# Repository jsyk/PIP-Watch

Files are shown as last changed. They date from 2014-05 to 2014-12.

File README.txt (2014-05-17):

----------------------------------------
Personal Information Panel - PIP Watch
----------------------------------------

Personal Information Panel – PIP Watch – is an open-source smart watch with an ePaper (EPD) display, a Bluetooth connection, and a Li-Ion accumulator.

This is a work in progress... For more information please visit:
http://www.jsykora.info/?page_id=328

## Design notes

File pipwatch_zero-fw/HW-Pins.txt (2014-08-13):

PA0     In      USART2_CTS
PA1     Out     USART2_RTS
PA2     Out     USART2_TX
PA3     In      USART2_RX

PA4     Out     GPIO EPD_nCS
PA5     Out     SPI1_SCK
PA6     In      GPIO Busy
PA7     Out     SPI1_MOSI

PB0     Ana     ADC_IN8 - Battery/5

PB2     Out     GPIO nRES
PB10    Out     GPIO EPD_DC

PB11    In      GPIO Btn0

PB13    Out     GPIO/TIM1_CH1N Motor_1

------
PC13    Out     Tamper-RTC

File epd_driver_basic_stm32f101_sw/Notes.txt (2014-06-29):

st-flash write stm32test_flash.bin 0x08000000

openocd -f interface/stlink-v2.cfg -f target/stm32f1x_stlink.cfg

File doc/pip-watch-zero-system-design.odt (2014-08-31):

Pip-Watch Zero: System Design

Pip-Watch Zero (Personal Information Panel) is an open-source smart watch with an ePaper (EPD) display, a bluetooth modem for connecting with smartphones, all powered by a Li-Ion accumulator.

...Show

Pip-Watch uses a small ePaper/eInk electrophoretic display (EPD). Electrophoretic displays have high contrast even in sun light, and very low power consumption, making them suitable for always-on battery-powered embedded devices. Low power consumption comes from the fact that the EPD draws no power when just displaying still image; it needs energy only when redrawing the screen.

...Talk

Communication with a mobile phone (or any internet-connected device) is via a Bluetooth modem module. As the modem implements the standard Bluetooth Serial Port Profile (SPP), Pip-Watch can be controlled over any terminal application even by hand. A smartphone app will transmit notifications to Pip-watch when an SMS arrives, a calendar event pops out, or an incoming call is being received.

...Eat
Pip-Watch is powered by a small Li-Ion accumulator that is recharged via a standard Micro USB connector. When connected, the USB can be also used to communicate with the device.

Hardware Block Schema

Hardware is built around the STM32F103 microcontroller. CPU timing is derived from an 8MHz crystal; it provides a clock stable enough for an on-chip USB interface to function correctly. An auxiliary low-speed precision 32.768kHz crystal is used for real-time clock (RTC), which is also included in the microcontroller.

Bluetooth modem is implemented by a pre-built commercial module. The first prototype uses OEMSPA310 from connectBlue, later the BTM431 from Laird will be used. The BTM431 has the advantage of lower power consumption and smaller size. These modules implement complete Bluetooth stack beginning with built-in ceramic antenna, and ending with a UART interface. Both modules are controlled via AT-style modem commands (albeit different between the types).

All power is normally delivered from Li-On battery, type Nokia BL-4C. The battery is charged form a Micro-USB connector via a charging controller MCP73831. The whole device runs at 3.3V, which is generated by a low-drop regulator LD59015C33R from a battery voltage. Current battery voltage is monitored by an A/D converter in the microcontroller, so the remaining battery charge can be computed and displayed on screen.

The display is implemented by GDE021A1, a small 3” electrophoretic display with the resolution 172x72 pixels. Communication with the display is via simple SPI-like interface. The display requires a charge pump with a coil and MOSFET.

Besides the display, the rest of human interface comprises of at least three buttons, three LEDs, and a vibrating motor(s) to give tactile notifications.

Software Block Schema

Software is organized in three layers. At the bottom there is a hardware access library from STM. The middle layer is composed mainly of the FreeRTOS operating system and a graphics drawing library u8g, both open-source. FreeRTOS is a simple multi-tasking operating system with pre-emptive scheduling, and with support for simple inter-task communication primitives such as queues and semaphores. The u8g is a drawing library: it is used to draw text and graphics such as lines and circles into a frame-buffer. The frame-buffer is then transmitted to the display.

The top software layer are tasks. The main tasks include a “Bluetooth Modem” task which communicates with a smartphone via Bluetooth, a “Battery” task that monitors battery charge using A/D converter, and a “Display Drawing” task that refreshes the display. Other tasks may be added as needed.

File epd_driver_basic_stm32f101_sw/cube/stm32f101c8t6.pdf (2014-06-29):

## stm32f101c8t6 Project

# 1. Description

## 1.1. Project

Project Name | stm32f101c8t6
Generated with: | STM32CubeMX 4.3.0
Date | 06/21/2014

## 1.2. MCU

MCU Serie | STM32F1
MCU Line | STM32F101
MCU name | STM32F101C8Tx
MCU Package | LQFP48
MCU Pin number | 48

# 2. Pinout Configuration

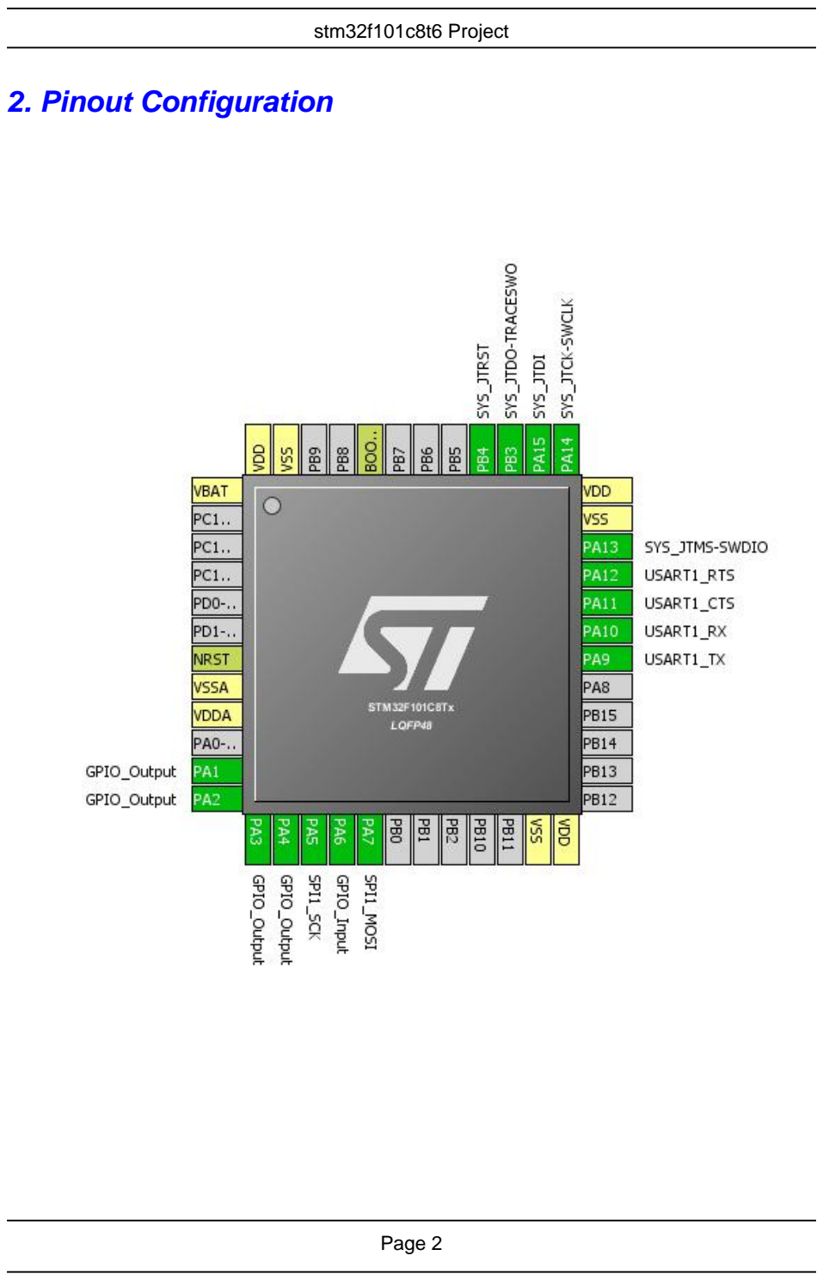
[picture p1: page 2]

# 3. IPs and Middlewares Configuration

IP | Mode | Fonction | Pin
SPI1 | Mode: TX-Only-Simplex-Unidirect-Master | SPI1_MOSI | PA7
| | SPI1_SCK | PA5
SYS | Debug: JTAG(5-pin) | SYS_JTCK-SWCLK | PA14
| | SYS_JTDI | PA15
| | SYS_JTDO-TRACESWO | PB3
| | SYS_JTMS-SWDIO | PA13
| | SYS_JTRST | PB4
USART1 | Mode: Hardware-flow-control | USART1_CTS | PA11
| | USART1_RTS | PA12
| | USART1_RX | PA10
| | USART1_TX | PA9

# 4. Pins Configuration

Pin | Pos Function(s) | | Label
PA1 * | 11 | GPIO_Output
PA2 * | 12 | GPIO_Output
PA3 * | 13 | GPIO_Output
PA4 * | 14 | GPIO_Output
PA5 | 15 | SPI1_SCK
PA6 * | 16 | GPIO_Input
PA7 | 17 | SPI1_MOSI
PA9 | 30 | USART1_TX
PA10 | 31 | USART1_RX
PA11 | 32 | USART1_CTS
PA12 | 33 | USART1_RTS
PA13 | 34 | SYS_JTMS-SWDIO
PA14 | 37 | SYS_JTCK-SWCLK
PA15 | 38 | SYS_JTDI
PB3 | 39 | SYS_JTDO-TRACESWO
PB4 | 40 | SYS_JTRST

## * The pin is affected with an I/O function

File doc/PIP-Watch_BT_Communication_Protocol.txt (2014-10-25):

PIP-Watch BT Communication Protocol
======================================

BTM430 Unsolicitated Messages
-------------------------------

The following messages may be sent by BTM430 at any time:

<cr,lf>AUDIO ON<cr,lf>
<cr,lf>AUDIO OFF<cr,lf>
<cr,lf>AUDIO FAIL<cr,lf>

<cr,lf>RING <btaddr><cr,lf>
<cr,lf>PIN? <btaddr><cr,lf>
<cr,lf>PAIR <n> <btaddr><cr,lf>
<cr,lf>PAIR 0 <btaddr> <MM><cr,lf>
<cr,lf>RX<string><cr,lf>
<cr,lf>CONNECT <btaddr><cr,lf>
<cr,lf>NO CARRIER<cr,lf>

Layers
-----------

Physical layer
    BTM431 BT modem

Link layer
    Transport of characters (bytes) via BT SPP link. - implemented in the modem.

Network layer
    Searching for nearby devices, enumeration, pairing, accepting connections.

Transport layer
    Transport of complete messages.

Session layer
    Synchronized exchange of messages between devices.
    Retransmission of lost messages.

Presentation layer

Application layer
    Transport of SMS etc.
    JSON

LINK STREAM LAYER
====================

<btm_rx_stream> :=
    { <btm_rx_msg> }*
    ON ERROR:
        a) eat till <lf>
        b) restart parser

<btm_rx_msg> :=
    . {<new_msg> | <msg_ack> | <msg_nack> | <btm_status>}

<new_msg> :=
    '*' <seqnum> <code_text> <lf>

<seqnum> :=
    <digit> <digit>

<msg_ack> :=
    '+' <seqnum> <lf>

<msg_nack> :=
    '-' <seqnum> <lf>

<btm_status> :=
    <cr><lf><status_text><cr><lf>

<code_text> := non-visible chars below space  must be code using escape secquence.
    Their presence here is either an error, or a token <cr>, <lf>.
    Escape sequences will be expanded in application (presentation) layer, not in the stream layer!

New Message:
-------------
*<seqnum><text...><lf>

<seqnum> = 00
    Two decimal numbers. Random number for the first message after connection,
    then incrementing, with a wrap.

<text>
    Max message length 2048 characters.
    Non-visible characters below space and the backslash are coded using \<2-hex-num>

Msg acknowledgement
-----------------------
+<seqnum><lf>

Msg nack
-----------
-<seqnum><lf>

APPLICATION LAYER
===================

Examples
===============

*01Ahoj<lf>

*01{"time":"2204"}<lf>

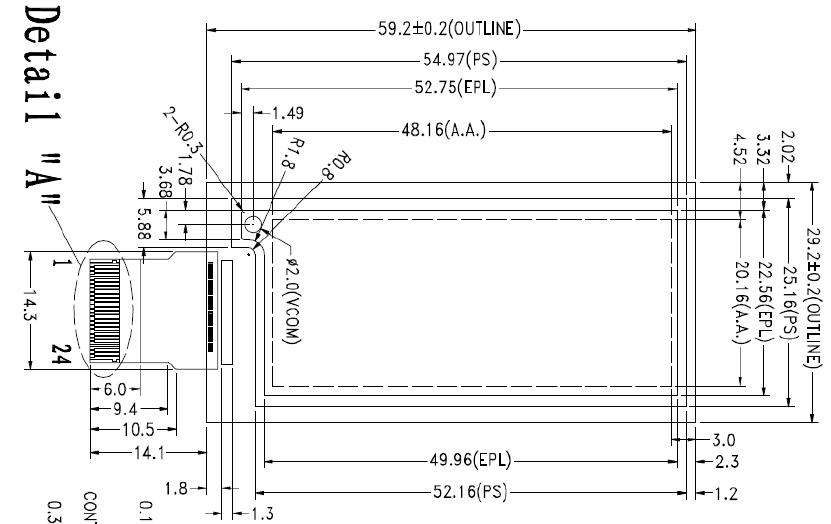
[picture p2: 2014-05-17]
doc/GDE021A1_mechanical.png

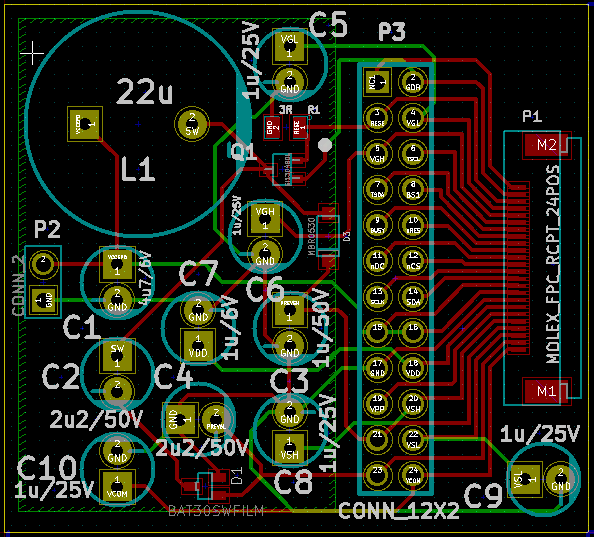
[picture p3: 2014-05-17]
doc/epd_driver_prototype_pcb.png

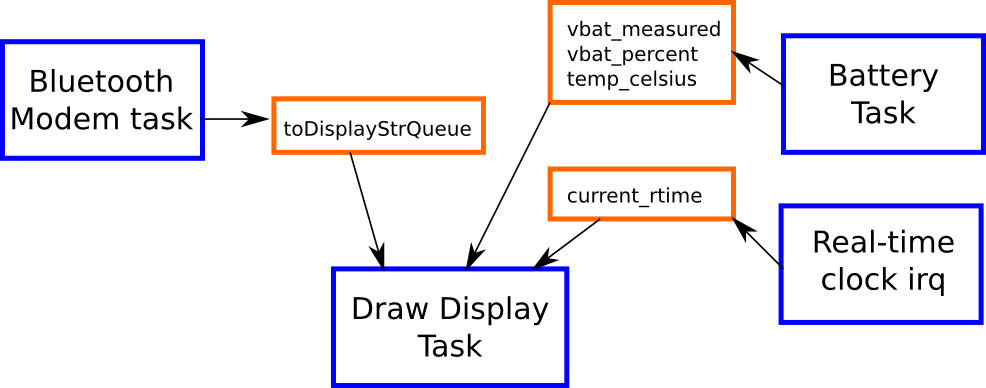
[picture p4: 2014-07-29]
doc/swtasks.png

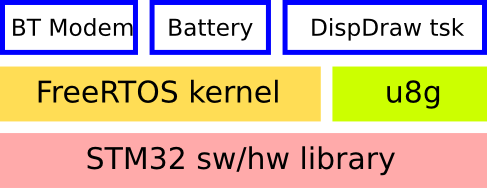
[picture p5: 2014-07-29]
doc/swarch.png

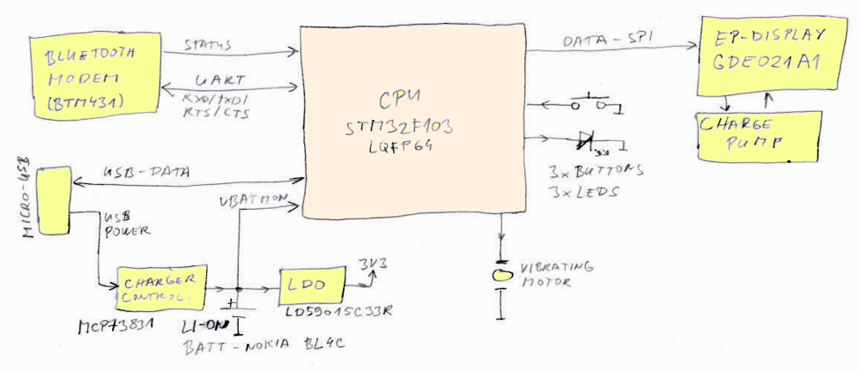
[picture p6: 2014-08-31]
doc/hw-block-schema.png

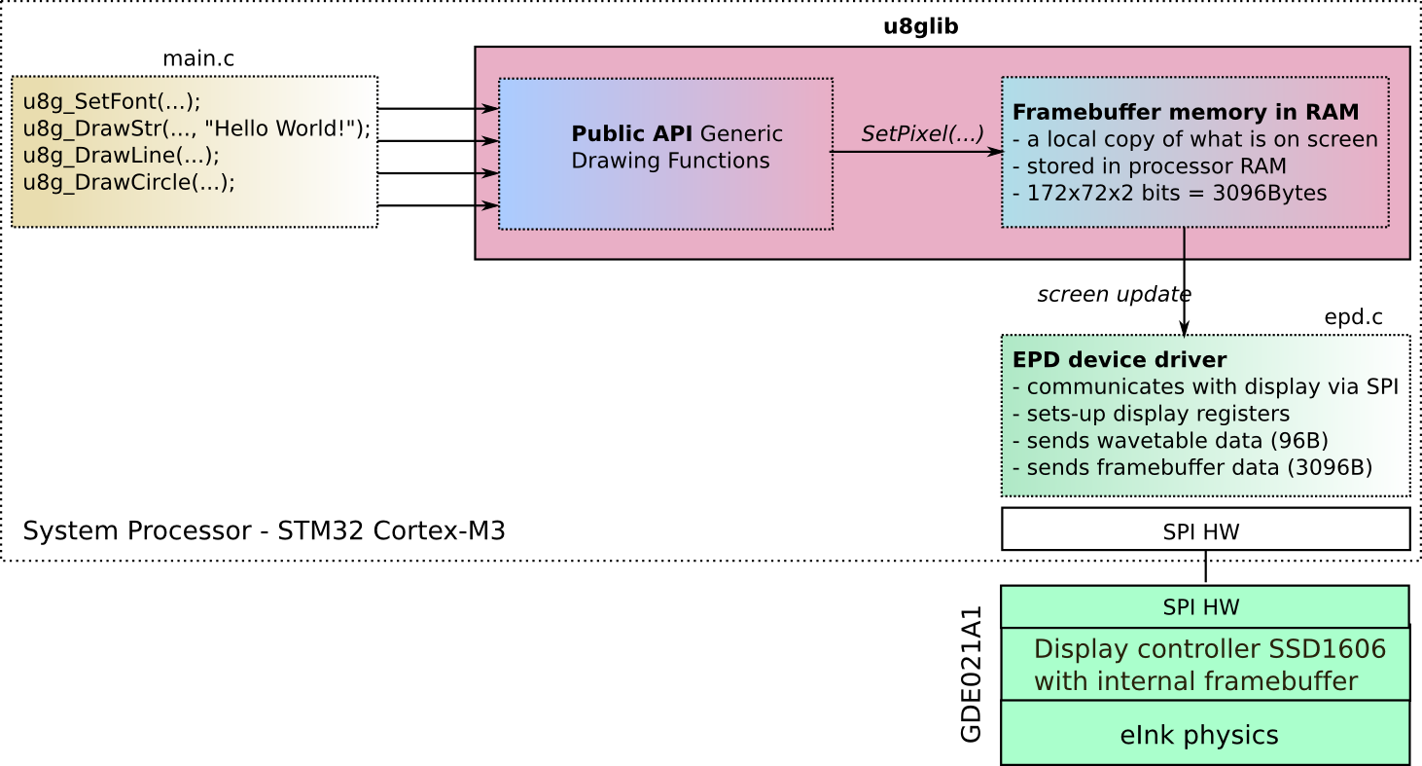
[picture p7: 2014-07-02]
doc/u8g_arch.png

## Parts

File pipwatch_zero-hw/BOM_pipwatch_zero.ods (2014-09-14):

Qty | Value | Footprint | Name | Refs | Supply 1
1 | BL4C |  | Nokia battery BL-4C | BAT201
2 | 12,5p | 0805 | CKS0805 12p/50V NPO SAM 5% | C401 C402 | http://www.gme.cz/cks0805-12p-50v-npo-sam-5-p906-005
2 | 18p | 0805 | CKS0805 18p/50V NPO YAG 5% | C403 C404 | http://www.gme.cz/cks0805-18p-50v-npo-yag-5-p906-010
10 | 100n | 0805 | CKS0805 100n/50V X7R YAG 10% | C405 C406 C407 C408 C409 C410 C411 C412 C413 C501 | http://www.gme.cz/cks0805-100n-50v-x7r-yag-10-p906-096
5 | 1u/50V | 1206 | CKS1206 1u/50V X7R HIT 10% | C302 C303 C304 C311 C312 | http://www.gme.cz/cks1206-1u-50v-x7r-hit-10-p905-014
6 | 1u/25V | 0805 | CKS0805 1u/25V X7R YAG 10% | C305 C306 C307 C308 C309 C310 | http://www.gme.cz/cks0805-1u-25v-x7r-yag-10-p905-183
5 | 4u7 | 1206 | CKS1206 4,7u/16V X7R HIT 10% | C201 C202 C203 C204 C301 | http://www.gme.cz/cks1206-4-7u-16v-x7r-hit-10-p905-195
2 | STPS1L30U | DO-214AA(SMB) | STMICROELECTRONICS - STPS1L30U - DIODE, SCHOTTKY, 1A, 30V, SMD, SMB | D202 D203 | http://cz.farnell.com/jsp/search/productdetail.jsp?SKU=1467550
2 | MBR0530 | sod123 | ON SEMICONDUCTOR - MBR0530T1G - DIODE, SCHOTTKY, 0.5A, 30V, SOD-123 | D302 D401 | http://cz.farnell.com/jsp/search/productdetail.jsp?SKU=1431036
4 | LED_RGB_AN | WURTH_LED4SMD | WURTH ELEKTRONIK - 150141M173100 - LED, 1411, RGB, 270MCD/950MCD/230MCD | D402 D403 D404 D201 | http://cz.farnell.com/jsp/search/productdetail.jsp?SKU=2322115
1 | BAT30SWFILM | SOT323 | STMICROELECTRONICS - BAT30SWFILM - DIODE, SCHOTTKY, 30V, DUAL SOT-323 | D301 | http://cz.farnell.com/jsp/search/productdetail.jsp?SKU=1749247
1 | 22uH | 1210 | Tlumivka SMD FASTRON TL.22µH SMD 10% | L301 | http://www.gme.cz/tlumivka-smd-fastron-tl-22uh-smd-10-p965-011
1 | CONN_1 | 1PIN_SMD | (RTC test point) | P401 | N/A
1 | CONN_2 | pin_strip_2 | (Motor) | P402 | N/A
1 | CONN_10 | PINARRAY_10P_2MM_SMD | Dutinková lišta BTK1N10, 2mm*10pin | P403 | http://www.gme.cz/dutinkova-lista-btk1n10-p832-257
1 | BC849 | SOT23EBC | BC849C | Q401 | http://www.gme.cz/bc849c-p912-012
1 | Si1304BDL | sc70 | VISHAY SILICONIX - SI1304BDL-T1-E3 - MOSFET, N CH, 30V, 0.9A, SC-70 | Q301 | http://cz.farnell.com/jsp/search/productdetail.jsp?SKU=2101433
1 | 3R | 0603 | R0603 3R3 1% | R301 | http://www.gme.cz/r0603-3r3-1-p901-712
1 | 33R | 0603 | R0603 33R 1% | R402 | http://www.gme.cz/r0603-33r-1-p901-477
8 | 330 | 0603 | R0603 330R 1% | R403 R405 R406 R408 R409 R411 R202 R203 | http://www.gme.cz/r0603-330r-1-p901-493
4 | 470 | 0603 | R0603 470R 1% | R404 R407 R410 R201 | http://www.gme.cz/r0603-470r-1-p901-495
1 | 4k7 | 0603 | R0603 4K7 1% | R401 | http://www.gme.cz/r0603-4k7-1-p901-509
1 | 10k | 0603 | R0603 10K 1% | R204 | http://www.gme.cz/r0603-10k-1-p901-399
2 | 47k | 0603 | R0603 47K 1% | R205 R206 | http://www.gme.cz/r0603-47k-1-p901-522
1 | TL1014BF180QG | PUSH_SMD_TL1014 | E-SWITCH - TL1014BF180QG - SWITCH, TACTILE, SPST, 0.05A, SMD | SW401 | http://cz.farnell.com/jsp/search/productdetail.jsp?SKU=2103641
3 | FSM4JSMATR | PUSH_SMD_FSM4JSMATR | TE CONNECTIVITY / ALCOSWITCH - FSM4JSMATR - SWITCH, TACTILE SPST, 0.05A, OUTSIDE L | SW402 SW403 SW404 | http://cz.farnell.com/jsp/search/productdetail.jsp?SKU=2292960
1 | BTM431 | BTM431 | LAIRD TECHNOLOGIES - BTM431 - BLUETOOTH MOD, AT DATA, INT ANTENNA | U501 | http://cz.farnell.com/jsp/search/productdetail.jsp?SKU=1857737
1 | STM32F103RXT | lqfp64 | STMICROELECTRONICS - STM32F103RCT6 - MCU, 32BIT, CORTEX-M3, 72MHZ, LQFP-64 | U401 | http://cz.farnell.com/stmicroelectronics/stm32f103rct6/mcu-32bit-cortex-m3-72mhz-lqfp/dp/1624136
1 | MICRO-B_USB | MICRO-B_USB | FCI - 10103594-0001LF - MICRO USB B, RECEPTACLE, SMT, RA, 5WAY | U201 | http://cz.farnell.com/jsp/search/productdetail.jsp?SKU=2293752
1 | USB6BX | SO8N | STMICROELECTRONICS - USB6B1RL - ESD PROTECTION ARRAY, SOIC-8 | U202 | http://cz.farnell.com/jsp/search/productdetail.jsp?SKU=2341651
1 | MCP73831 | SOT23-5 | MICROCHIP - MCP73831T-2DCI/OT - IC, BATT MGMT, LI-ION/LI-POLY, SOT23-5 | U203 | http://cz.farnell.com/microchip/mcp73831t-2dci-ot/ic-batt-mgmt-li-ion-li-poly-sot23/dp/1840935
1 | LD59015C33R | SOT323-5 | STMICROELECTRONICS - LD59015C33R - V REG, 2.3-5.5V, 0.15A, 3.3V, 5SOT323 | U204 | http://cz.farnell.com/stmicroelectronics/ld59015c33r/v-reg-2-3-5-5v-0-15a-3-3v-5sot323/dp/2311335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
1 | MOLEX_FPC_RCPT_24POS | MOLEX_FPC_RCPT_24POS | MOLEX - 52435-2471 - CONNECTOR, FPC, RCPT, 24POS, 1ROW | X301 | http://cz.farnell.com/jsp/search/productdetail.jsp?sku=2396220
1 | CM309S8.000MABJ | XTAL_CM309S | CITIZEN FINETECH MIYOTA - CM309S8.000MABJ-UT - CRYSTAL 8MHZ | X402 | http://cz.farnell.com/jsp/search/productdetail.jsp?SKU=1703587
1 | ABS25-32.768 | XTAL_ABS25 | ABRACON - ABS25-32.768KHZ-1-T - CRYSTAL, 32.768KHZ, 12.5PF, SMD | X401 | http://cz.farnell.com/jsp/search/productdetail.jsp?SKU=2308714
1 | P-TS1107GS | PUSH_SMD_TS1107GS | P-TS1107GS | SW405 SW406 | http://www.gme.cz/p-ts1107gs-p630-275

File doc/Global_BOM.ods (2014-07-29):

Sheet: BOM
Qty | Type | Name | Manuf. | Supplier
1 | GDE021A1 | EPD Display | http://www.good-display.com/products_detail/&productId=07992b88-6ac5-4a0e-ba84-d7cadcd55ebe.html
1 | cB-OEMSPA310i-04 | BT Serial adapter | connectBlue
1 | MOLEX 52435-2471 | Conn. FPC RCPT 24POS 1ROW 0.5MM |  | http://cz.farnell.com/jsp/search/productdetail.jsp?sku=2396220
 |  | SXT SXT-1434 Flat Vibrating Vibration Motor – Silver |  | http://www.dx.com/p/sxt-sxt-1434-flat-vibrating-vibration-motor-silver-5pcs-306114#.U3pu4q4-ZUI
1 | MCP73831T-2DCIOT | LiOn Charger, 4,2V | Microchip

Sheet: Tools
Type | Name | Manuf. | Supplier
J-LINK | J-Link V8 ARM USB-JTAG Adapter Emulator | http://www.dx.com/p/j-link-v8-arm-usb-jtag-adapter-emulator-black-149039#.U3pJEK4-ZUJ
 | ARM Cortex-M3 STM32F103C8T6 STM32 Development Board - Blue + Black | http://www.dx.com/p/arm-cortex-m3-stm32f103c8t6-stm32-development-board-blue-black-198746
 | ChuangZhuo Male to Male / Male to Female / Female to Female Arduino DuPont Cable - (3 x 40 PCS) | http://eud.dx.com/product/chuangzhuo-male-to-male-male-to-female-female-to-female-arduino-dupont-cable-3-x-40-pcs-844278367

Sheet: Unused
Qty | Type | Name | Manuf. | Supplier
 | PAN1026-SPP+GATT | PANASONIC - PAN1026-SPP+GATT - RF MOD, TXRX, BLUETOOTH, TC35661, 2.4GHZ |  | http://cz.farnell.com/jsp/search/productdetail.jsp?sku=2325984
 | BLE112-A-V1 | BLUEGIGA - BLE112-A-V1 - BLUETOOTH MODULE, CLASS 2, CHIP ANT |  | http://cz.farnell.com/jsp/search/productdetail.jsp?sku=2113858 | BT4 Only single-mode
 | PAN1326-HCI-85 | PANASONIC - PAN1326-HCI-85 - RF MOD, TXRX, BLUETOOTH, CC2564, 2.4GHZ |  | http://cz.farnell.com/jsp/search/productdetail.jsp?sku=2325982

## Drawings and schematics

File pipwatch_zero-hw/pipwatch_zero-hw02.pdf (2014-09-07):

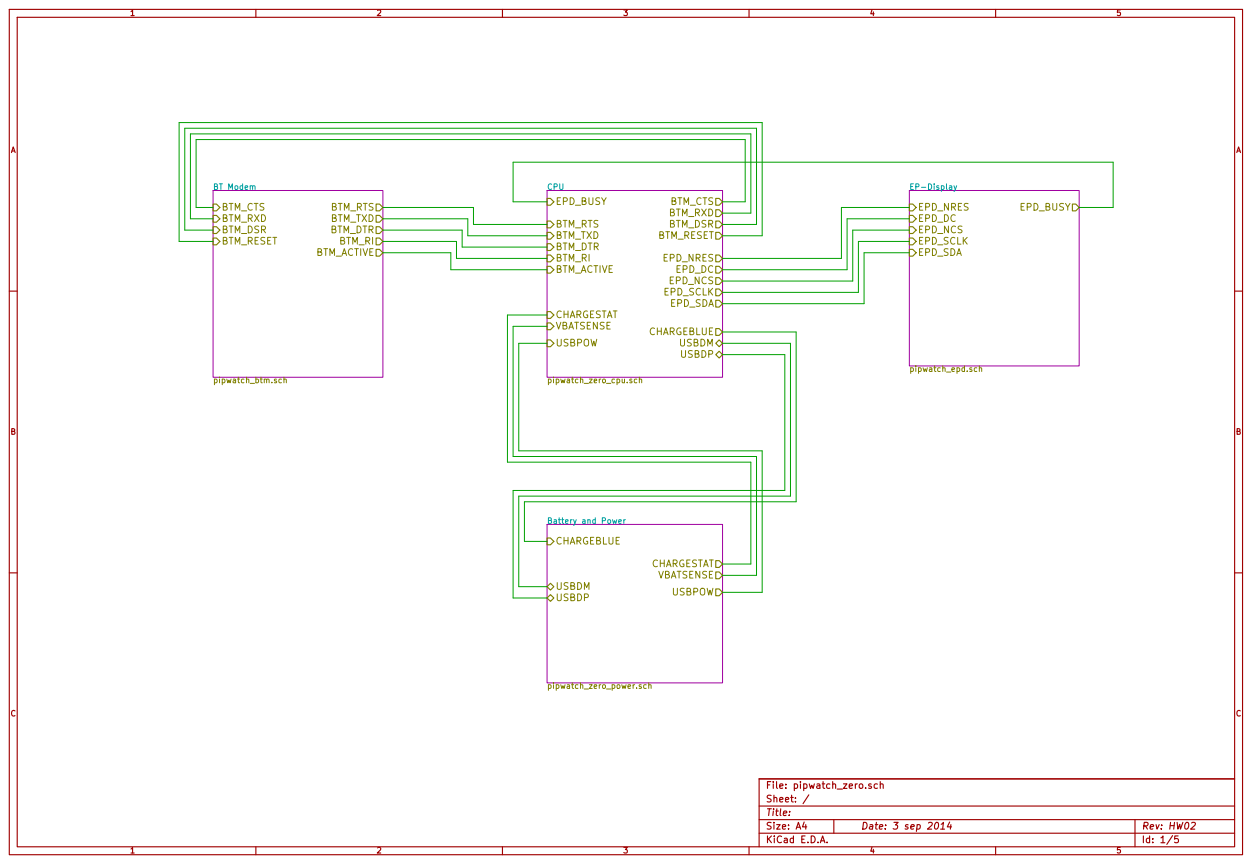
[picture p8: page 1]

Id: 1/5 Title: File: pipwatch_zero.sch
Sheet: /

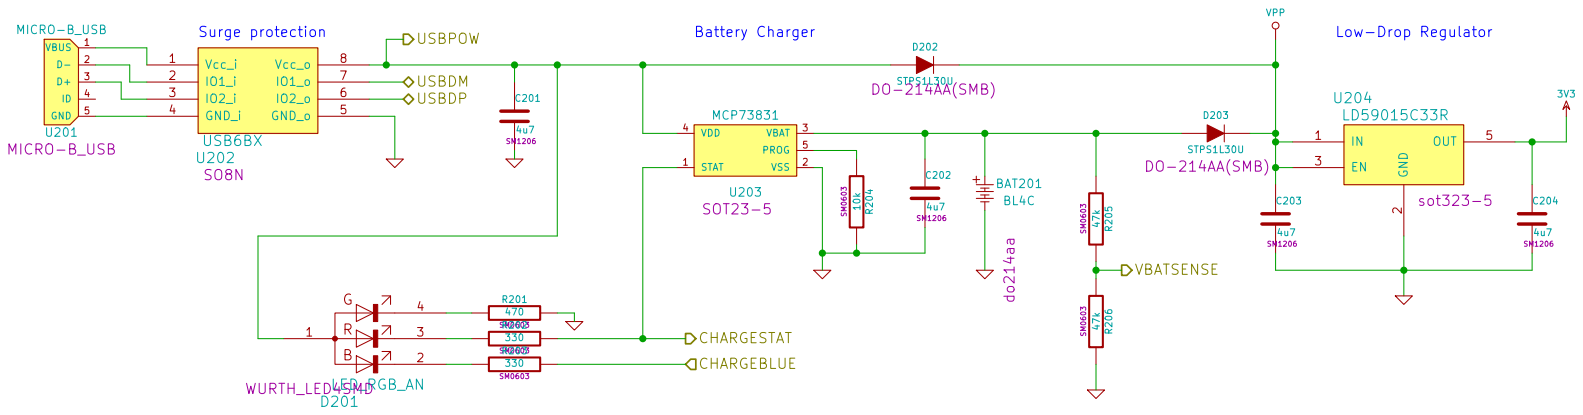
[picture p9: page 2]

ID 4 GND 5 U201 MICRO-B_USB MICRO-B_USB

File: pipwatch_zero_power.sch
Sheet: /Battery and Power/
Title: PIPWATCH ZERO

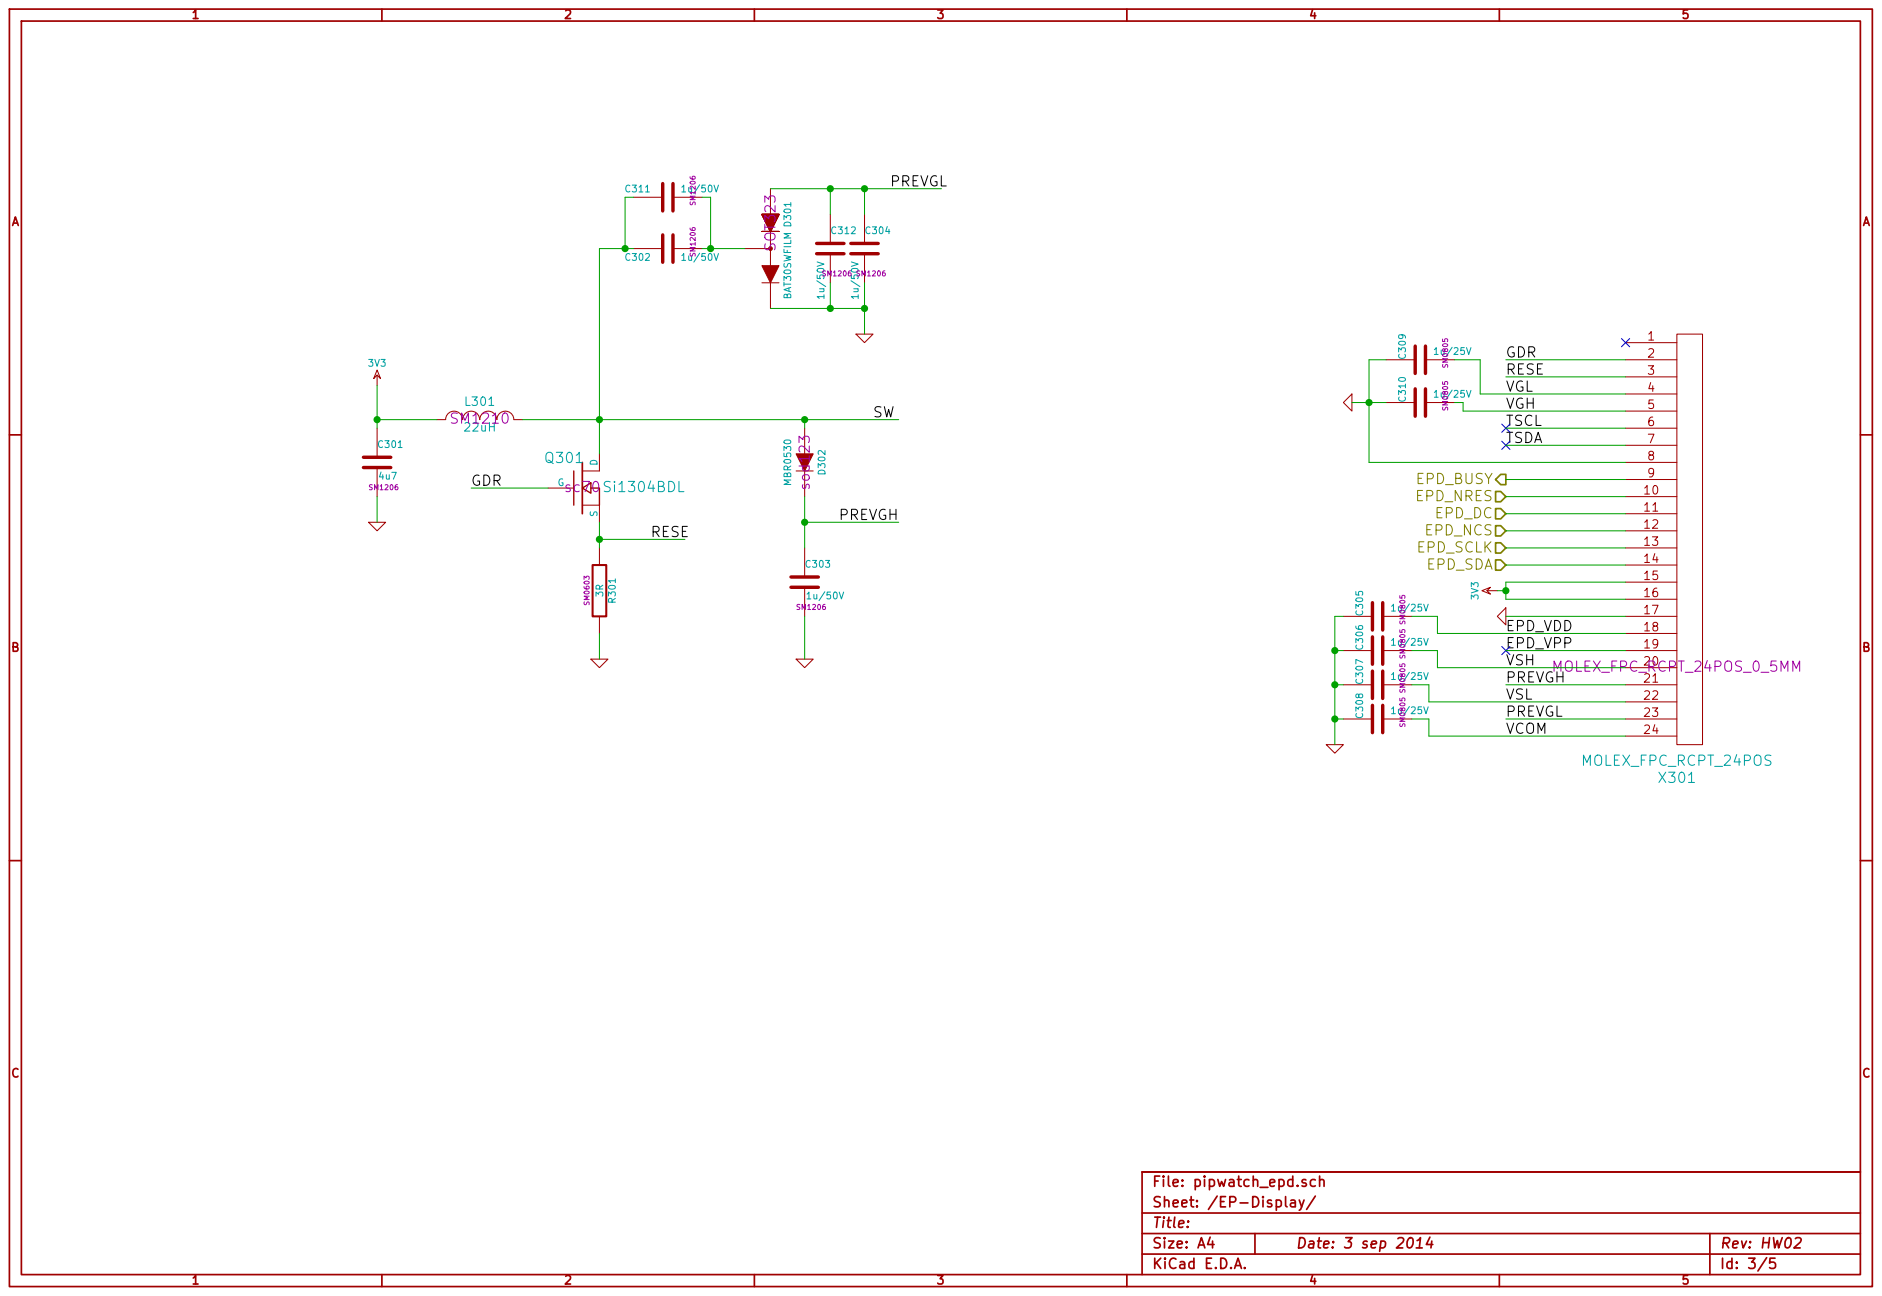
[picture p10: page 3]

Id: 3/5 Title: File: pipwatch_epd.sch
Sheet: /EP-Display/

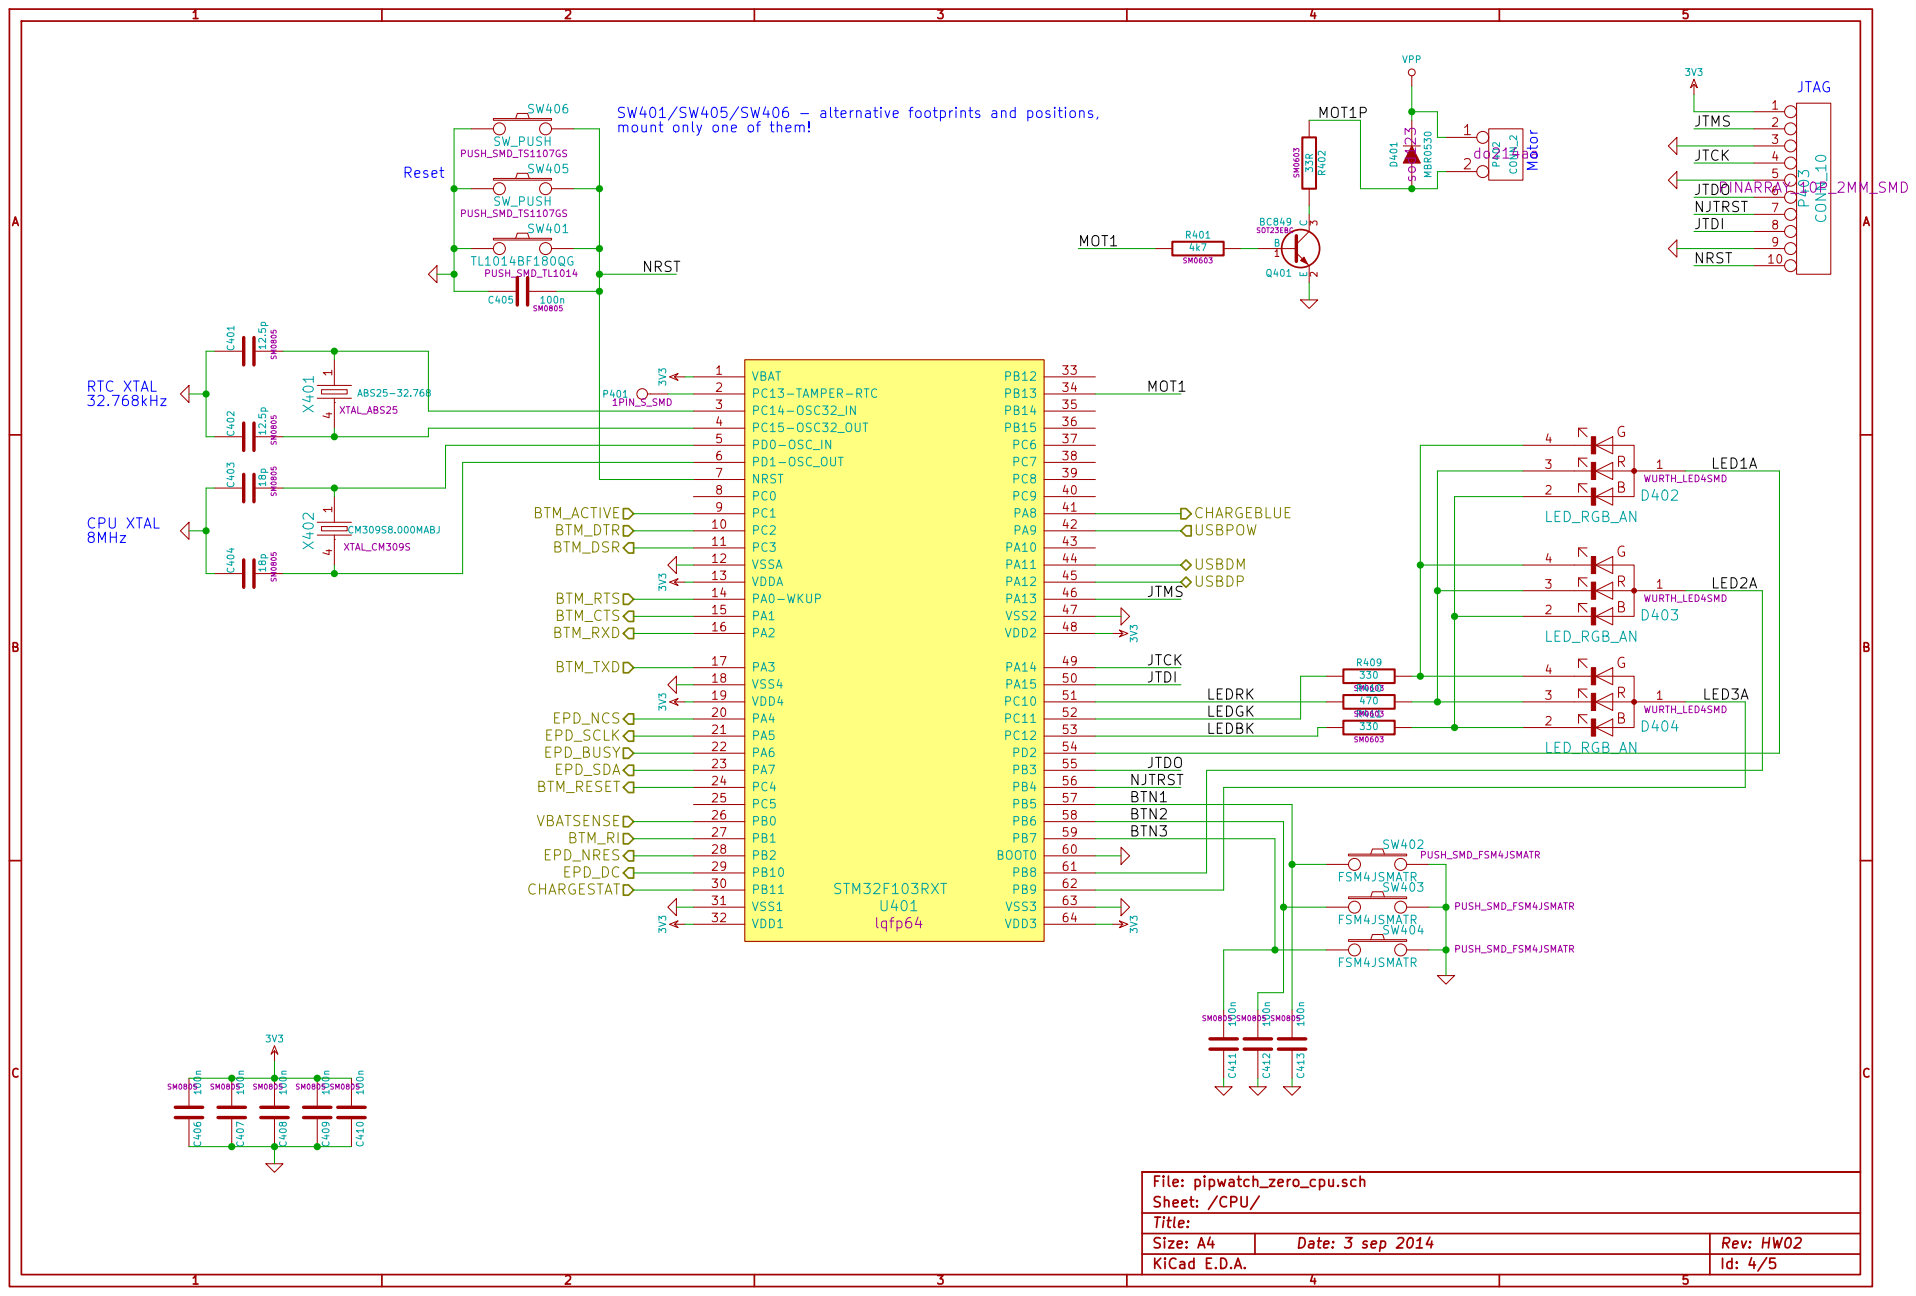
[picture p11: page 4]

mount only one of them! SW406 SW_PUSH

3 | WURTH_LED4SMD R409

LEDGK | | 2
LEDBK | 330

Id: 4/5 Title: File: pipwatch_zero_cpu.sch
Sheet: /CPU/

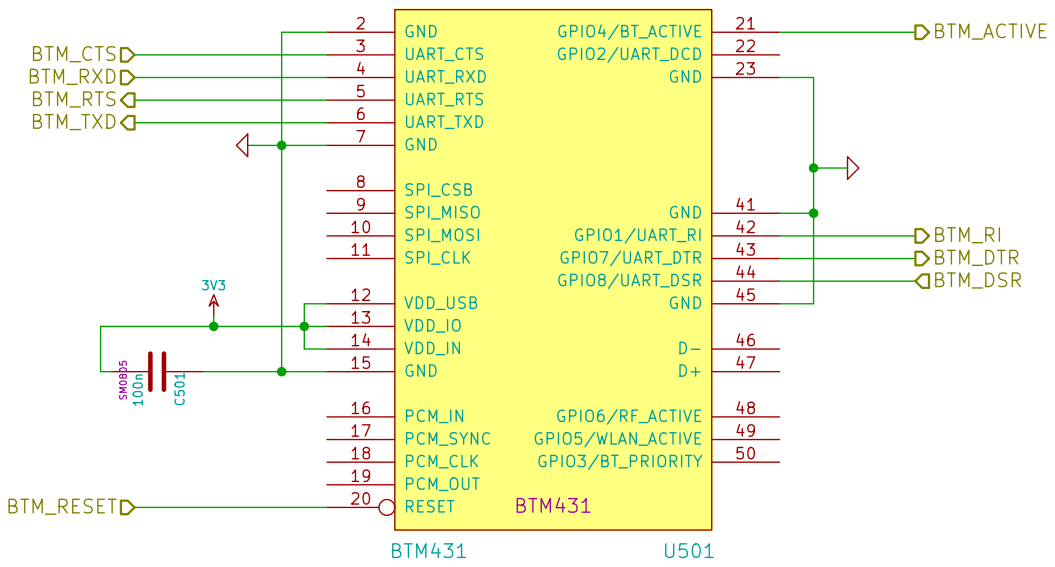
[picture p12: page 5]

Id: 5/5 Title: File: pipwatch_btm.sch
Sheet: /BT Modem/

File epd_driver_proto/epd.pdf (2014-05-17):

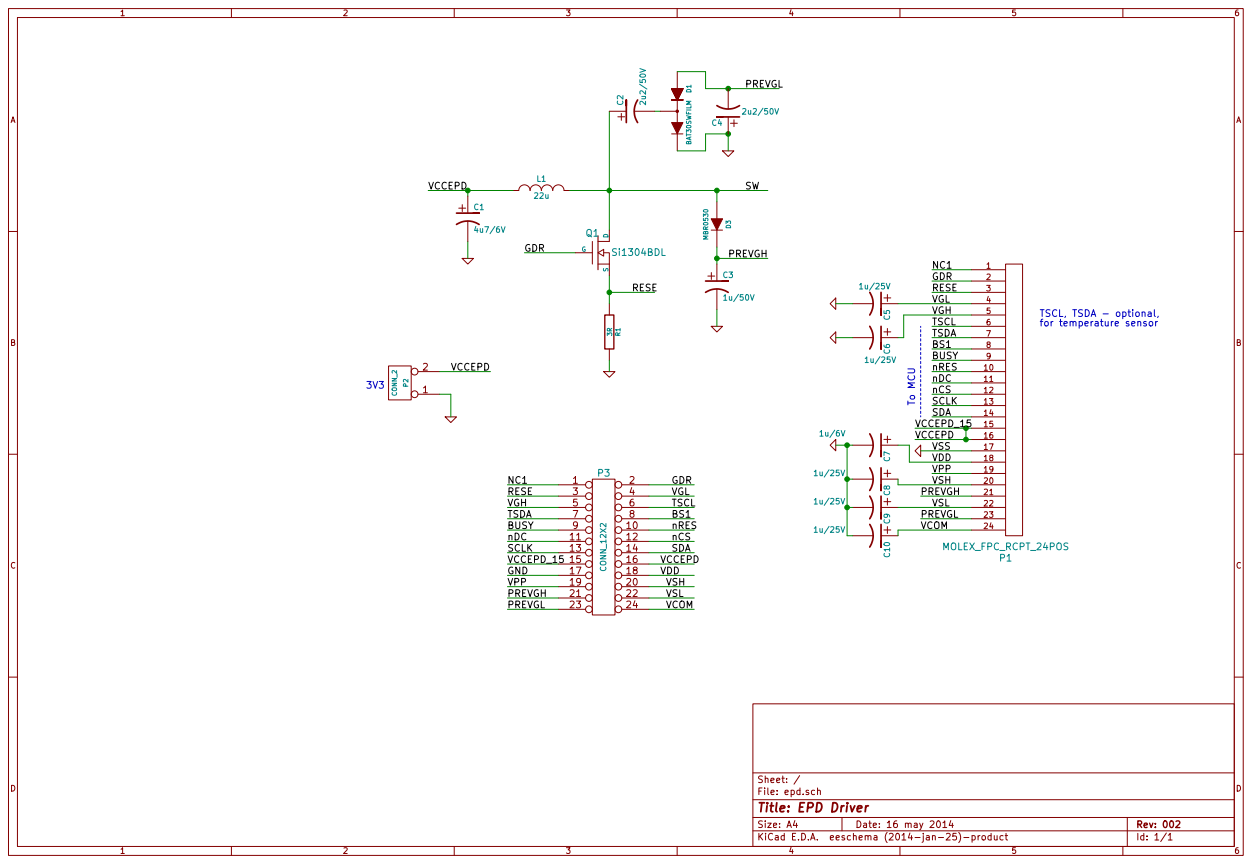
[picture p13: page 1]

VGH | 5
TSCL | 6

for temperature sensor To MCU
TSDA

Id: 1/1 Title: EPD Driver

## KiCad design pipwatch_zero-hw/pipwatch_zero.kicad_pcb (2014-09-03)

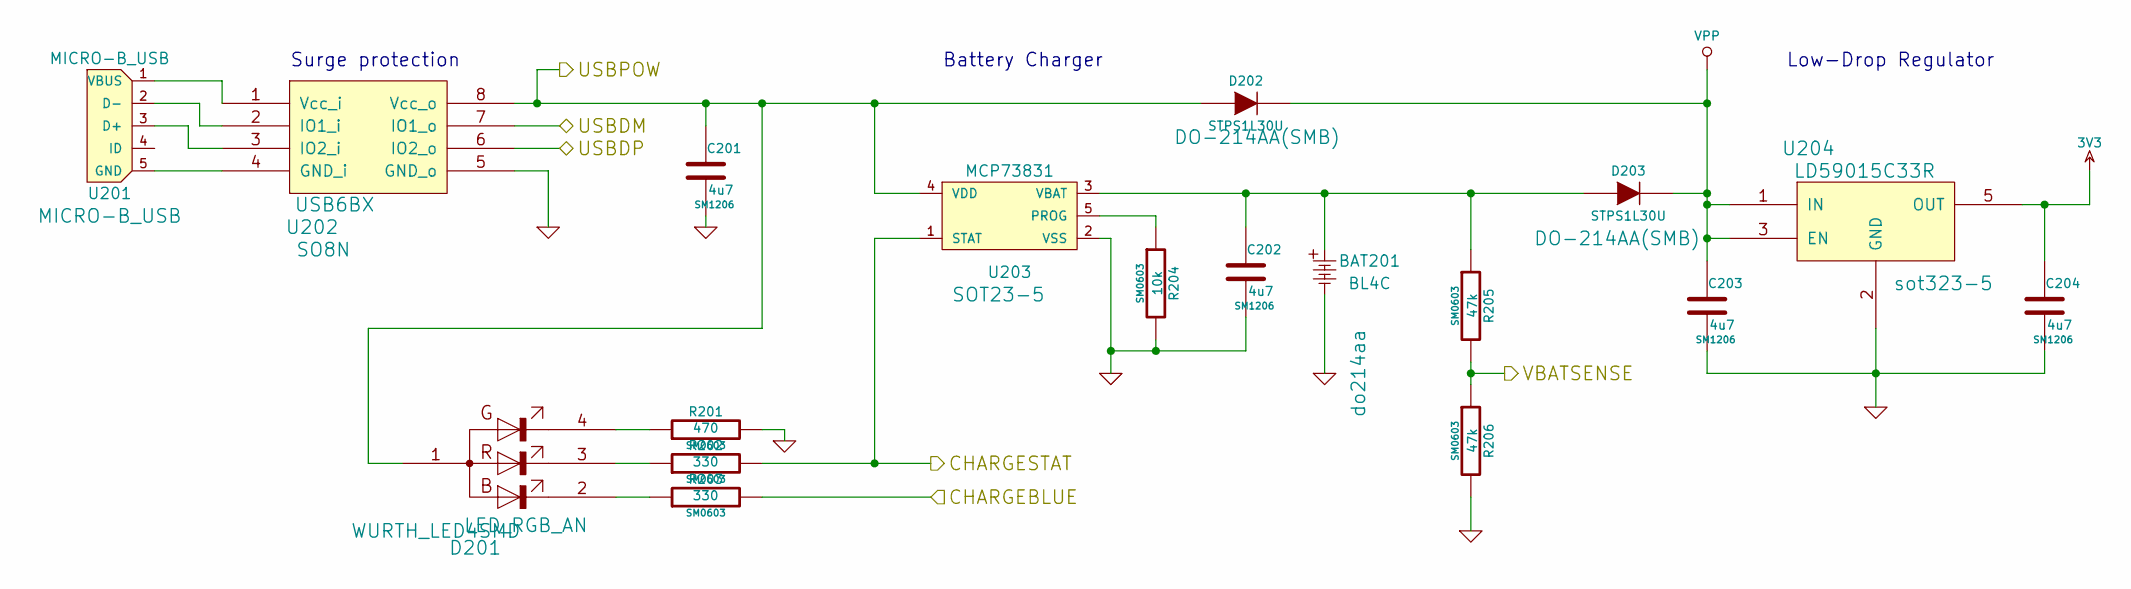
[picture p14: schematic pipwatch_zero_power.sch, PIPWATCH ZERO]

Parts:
BAT201: BL4C; do214aa
C201, C202, C203, C204: 4u7; SM1206
D201: LED_RGB_AN; WURTH_LED4SMD
D202, D203: STPS1L30U; DO-214AA(SMB)
R201: 470; SM0603
R202, R203: 330; SM0603
R204: 10k; SM0603
R205, R206: 47k; SM0603
U201: MICRO-B_USB
U202: USB6BX; SO8N
U203: MCP73831; SOT23-5
U204: LD59015C33R; sot323-5

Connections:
3V3: C204.1, U204.5 (OUT); also elsewhere on the board
/Battery and Power/CHARGEBLUE: R203.2; also elsewhere on the board
/Battery and Power/CHARGESTAT: R202.2, U203.1 (STAT); also elsewhere on the board
/Battery and Power/USBDM: U202.7 (IO1_o); also elsewhere on the board
/Battery and Power/USBDP: U202.6 (IO2_o); also elsewhere on the board
/Battery and Power/USBPOW: C201.1, D201.1, D202.1 (A), U202.8 (Vcc_o), U203.4 (VDD); also elsewhere on the board
/Battery and Power/VBATSENSE: R205.2, R206.1; also elsewhere on the board
GND: BAT201.2, C201.2, C202.2, C203.2, C204.2, R201.2, R204.2, R206.2, U202.5 (GND_o), U203.2 (VSS), U204.2 (GND); also elsewhere on the board
unnamed: R204.1, U203.5 (PROG)
unnamed: D201.4, R201.1
unnamed: D201.3, R202.1
unnamed: D201.2, R203.1
unnamed: U201.3 (D+), U202.3 (IO2_i)
unnamed: U201.2 (D-), U202.2 (IO1_i)
unnamed: U201.1 (VBUS), U202.1 (Vcc_i)
unnamed: U201.5 (GND), U202.4 (GND_i)
unnamed: BAT201.1, C202.1, D203.1 (A), R205.1, U203.3 (VBAT)
VPP: C203.1, D202.2 (K), D203.2 (K), U204.1 (IN), U204.3 (EN); also elsewhere on the board

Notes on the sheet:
Surge protection
Battery Charger
Low-Drop Regulator

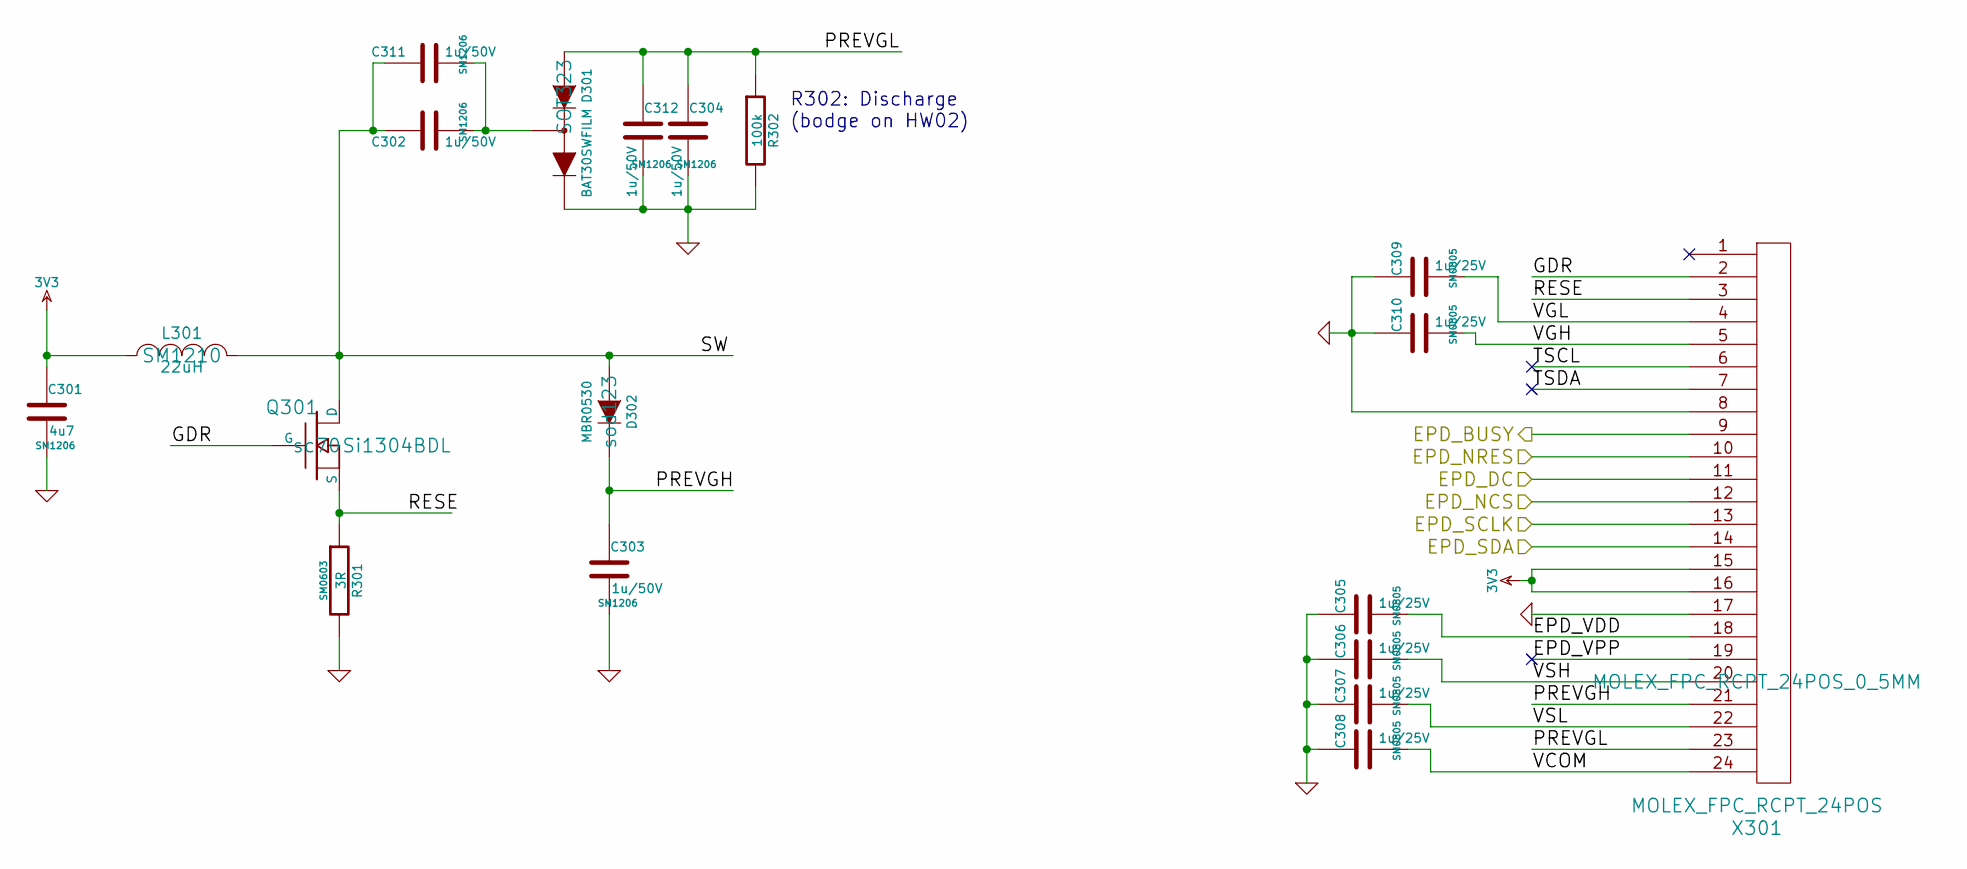
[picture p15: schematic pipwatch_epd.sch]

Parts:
C301: 4u7; SM1206
C302, C303, C304, C311, C312: 1u/50V; SM1206
C305, C306, C307, C308, C309, C310: 1u/25V; SM0805
D301: BAT30SWFILM; SOT323
D302: MBR0530; sod123
L301: 22uH; SM1210
Q301: Si1304BDL; sc70
R301: 3R; SM0603
R302: 100k
X301: MOLEX_FPC_RCPT_24POS; MOLEX_FPC_RCPT_24POS_0_5MM

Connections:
3V3: C301.1, L301.1, X301.15, X301.16; also elsewhere on the board
/CPU/EPD_BUSY: X301.9; also elsewhere on the board
/CPU/EPD_DC: X301.11; also elsewhere on the board
/CPU/EPD_NCS: X301.12; also elsewhere on the board
/CPU/EPD_NRES: X301.10; also elsewhere on the board
/CPU/EPD_SCLK: X301.13; also elsewhere on the board
/CPU/EPD_SDA: X301.14; also elsewhere on the board
/EP-Display/EPD_VDD: C305.2, X301.18
/EP-Display/GDR: Q301.1 (G), X301.2
/EP-Display/PREVGH: C303.1, D302.2 (K), X301.21
/EP-Display/PREVGL: C304.1, C312.1, D301.1 (A), R302.1, X301.23
/EP-Display/RESE: Q301.3 (S), R301.1, X301.3
/EP-Display/SW: C302.1, C311.1, D302.1 (A), L301.2, Q301.2 (D)
/EP-Display/VCOM: C308.2, X301.24
/EP-Display/VGH: C310.2, X301.5
/EP-Display/VGL: C309.2, X301.4
/EP-Display/VSH: C306.2, X301.20
/EP-Display/VSL: C307.2, X301.22
GND: C301.2, C303.2, C304.2, C305.1, C306.1, C307.1, C308.1, C309.1, C310.1, C312.2, D301.2 (K), R301.2, R302.2, X301.8, X301.17; also elsewhere on the board
unnamed: C302.2, C311.2, D301.3 (Com)

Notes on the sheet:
R302: Discharge (bodge on HW02)

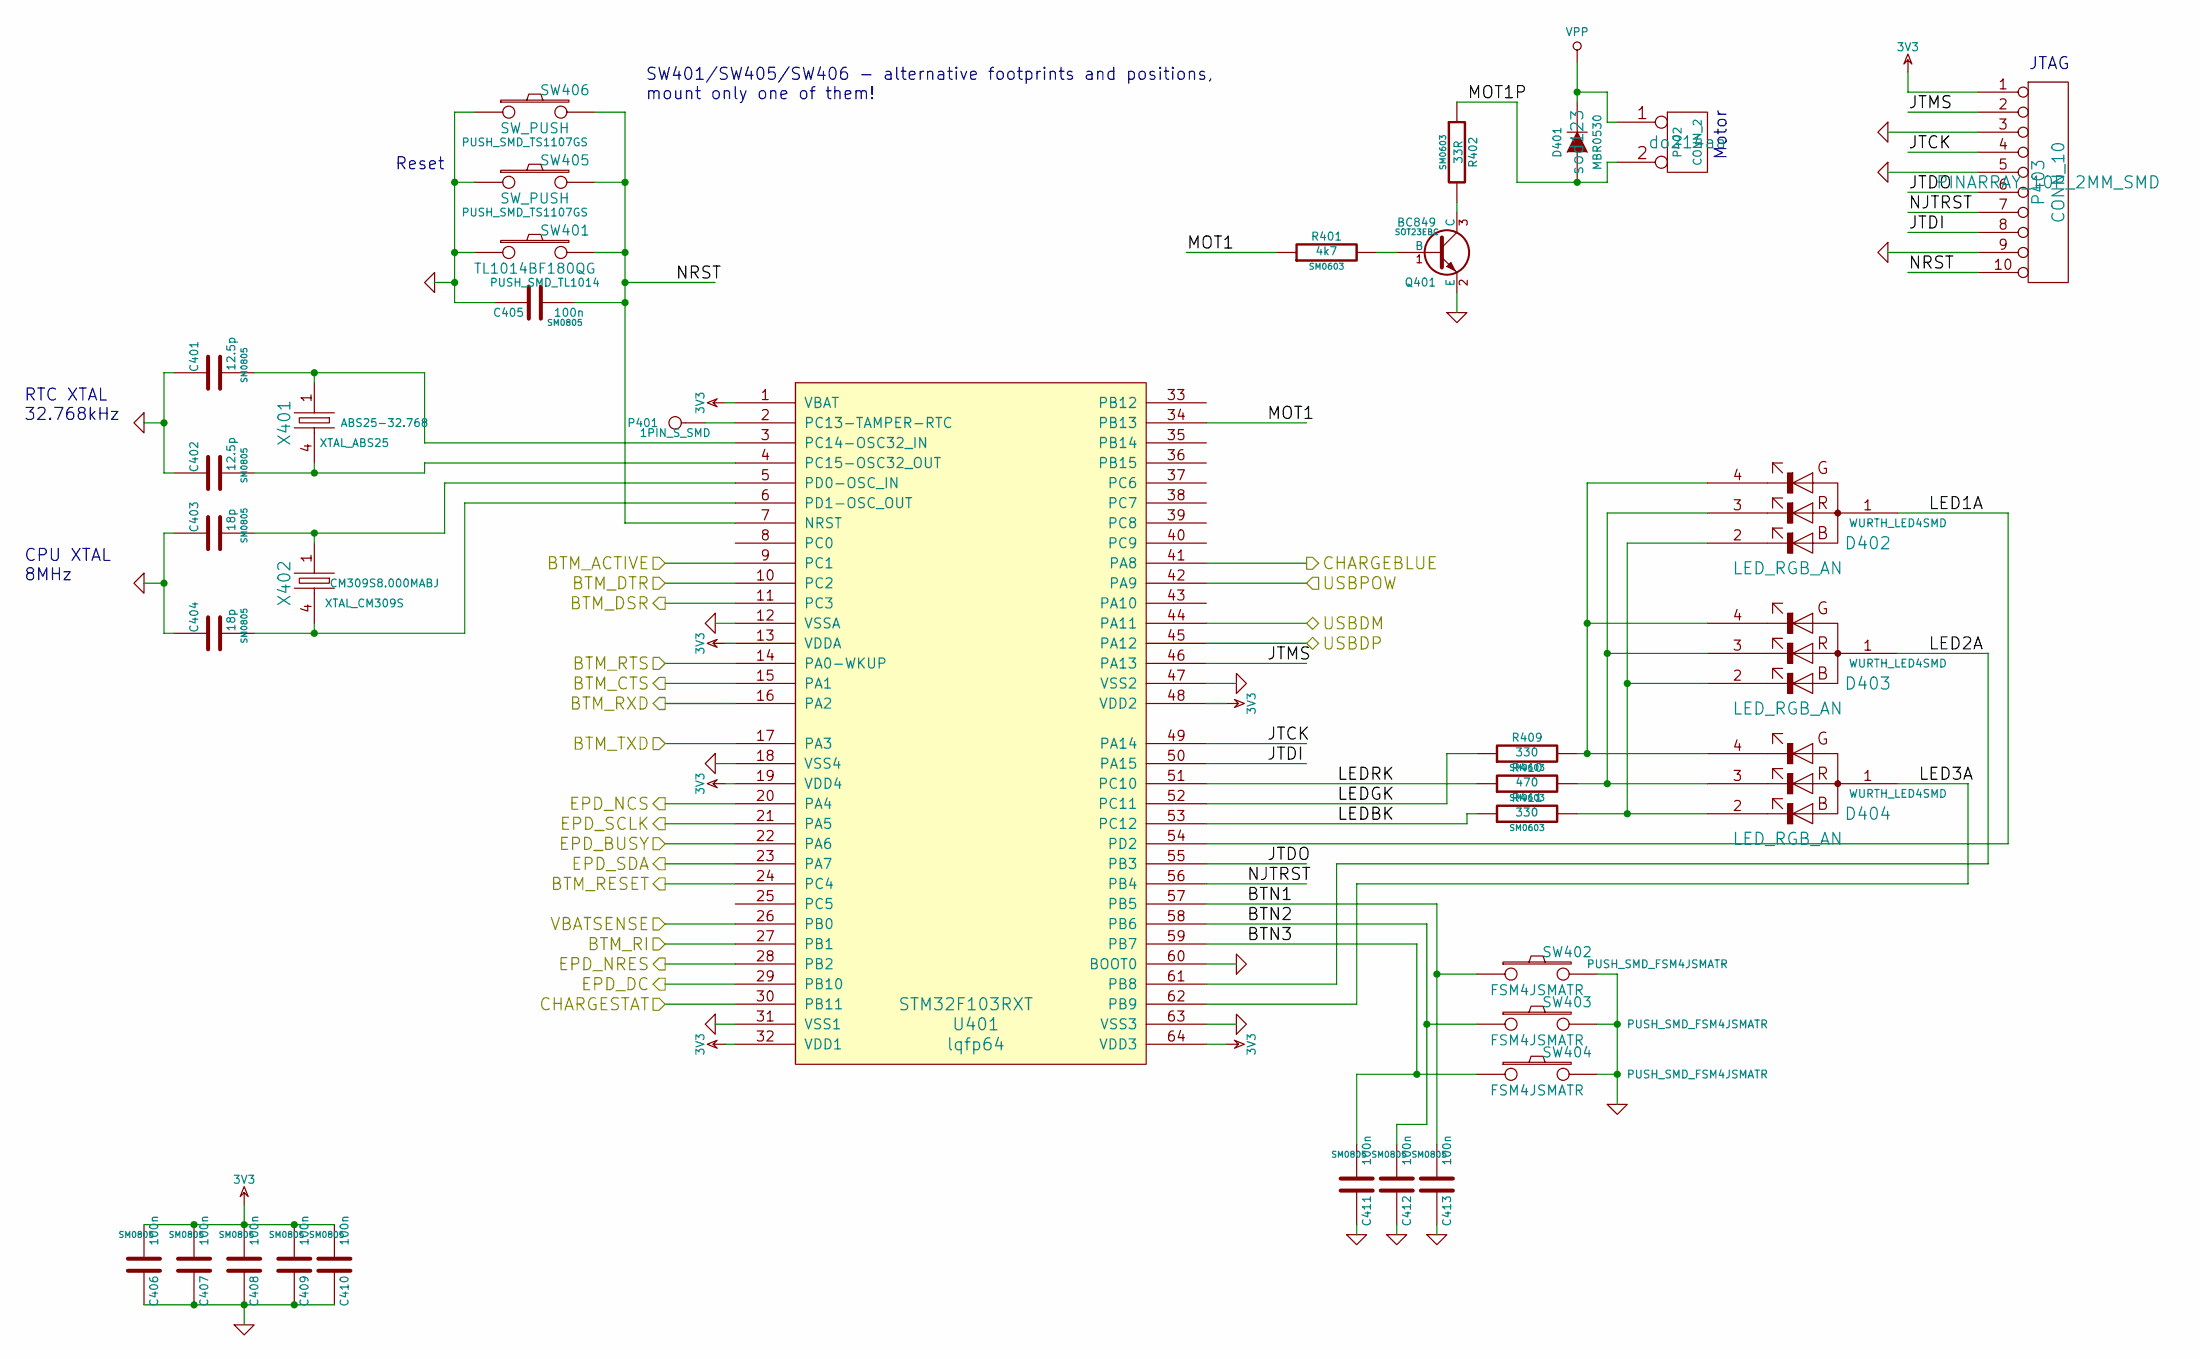
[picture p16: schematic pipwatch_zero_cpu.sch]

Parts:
C401, C402: 12.5p; SM0805
C403, C404: 18p; SM0805
C405, C406, C407, C408, C409, C410, C411, C412, C413: 100n; SM0805
D401: MBR0530; sod123
D402, D403, D404: LED_RGB_AN; WURTH_LED4SMD
P401: CONN_1; 1PIN_S_SMD
P402: CONN_2; do214aa
P403: CONN_10; PINARRAY_10P_2MM_SMD
Q401: BC849; SOT23EBC
R401: 4k7; SM0603
R402: 33R; SM0603
R409, R411: 330; SM0603
R410: 470; SM0603
SW401: TL1014BF180QG; PUSH_SMD_TL1014
SW402, SW403, SW404: FSM4JSMATR; PUSH_SMD_FSM4JSMATR
SW405, SW406: SW_PUSH; PUSH_SMD_TS1107GS
U401: STM32F103RXT; lqfp64
X401: ABS25-32.768; XTAL_ABS25
X402: CM309S8.000MABJ; XTAL_CM309S

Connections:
3V3: C406.2, C407.2, C408.2, C409.2, C410.2, P403.1, U401.1 (VBAT), U401.13 (VDDA), U401.19 (VDD4), U401.32 (VDD1), U401.48 (VDD2), U401.64 (VDD3); also elsewhere on the board
/BT Modem/BTM_ACTIVE: U401.9 (PC1); also elsewhere on the board
/BT Modem/BTM_CTS: U401.15 (PA1); also elsewhere on the board
/BT Modem/BTM_DSR: U401.11 (PC3); also elsewhere on the board
/BT Modem/BTM_DTR: U401.10 (PC2); also elsewhere on the board
/BT Modem/BTM_RESET: U401.24 (PC4); also elsewhere on the board
/BT Modem/BTM_RI: U401.27 (PB1); also elsewhere on the board
/BT Modem/BTM_RTS: U401.14 (PA0-WKUP); also elsewhere on the board
/BT Modem/BTM_RXD: U401.16 (PA2); also elsewhere on the board
/BT Modem/BTM_TXD: U401.17 (PA3); also elsewhere on the board
/Battery and Power/CHARGEBLUE: U401.41 (PA8); also elsewhere on the board
/Battery and Power/CHARGESTAT: U401.30 (PB11); also elsewhere on the board
/Battery and Power/USBDM: U401.44 (PA11); also elsewhere on the board
/Battery and Power/USBDP: U401.45 (PA12); also elsewhere on the board
/Battery and Power/USBPOW: U401.42 (PA9); also elsewhere on the board
/Battery and Power/VBATSENSE: U401.26 (PB0); also elsewhere on the board
/CPU/BTN1: C413.2, SW402.1, U401.57 (PB5)
/CPU/BTN2: C412.2, SW403.1, U401.58 (PB6)
/CPU/BTN3: C411.2, SW404.1, U401.59 (PB7)
/CPU/EPD_BUSY: U401.22 (PA6); also elsewhere on the board
/CPU/EPD_DC: U401.29 (PB10); also elsewhere on the board
/CPU/EPD_NCS: U401.20 (PA4); also elsewhere on the board
/CPU/EPD_NRES: U401.28 (PB2); also elsewhere on the board
/CPU/EPD_SCLK: U401.21 (PA5); also elsewhere on the board
/CPU/EPD_SDA: U401.23 (PA7); also elsewhere on the board
/CPU/JTCK: P403.4, U401.49 (PA14)
/CPU/JTDI: P403.8, U401.50 (PA15)
/CPU/JTDO: P403.6, U401.55 (PB3)
/CPU/JTMS: P403.2, U401.46 (PA13)
/CPU/LED1A: D402.1, U401.54 (PD2)
/CPU/LED2A: D403.1, U401.61 (PB8)
/CPU/LED3A: D404.1, U401.62 (PB9)
/CPU/LEDBK: R411.1, U401.53 (PC12)
/CPU/LEDGK: R409.1, U401.52 (PC11)
/CPU/LEDRK: R410.1, U401.51 (PC10)
/CPU/MOT1: R401.1, U401.34 (PB13)
/CPU/MOT1P: D401.1 (A), P402.2 (PM), R402.1
/CPU/NJTRST: P403.7, U401.56 (PB4)
/CPU/NRST: C405.2, P403.10, SW401.2, SW405.2, SW406.2, U401.7 (NRST)
GND: C401.1, C402.1, C403.1, C404.1, C405.1, C406.1, C407.1, C408.1, C409.1, C410.1, C411.1, C412.1, C413.1, P403.3, P403.5, P403.9, Q401.2 (E), SW401.1, SW402.2, SW403.2, SW404.2, SW405.1, SW406.1, U401.12 (VSSA), U401.18 (VSS4), U401.31 (VSS1), U401.47 (VSS2), U401.60 (BOOT0), U401.63 (VSS3); also elsewhere on the board
unnamed: C401.2, U401.3 (PC14-OSC32_IN), X401.1
unnamed: C402.2, U401.4 (PC15-OSC32_OUT), X401.4
unnamed: Q401.1 (B), R401.2
unnamed: P401.1, U401.2 (PC13-TAMPER-RTC)
unnamed: D402.2, D403.2, D404.2, R411.2
unnamed: D402.3, D403.3, D404.3, R410.2
unnamed: D402.4, D403.4, D404.4, R409.2
unnamed: Q401.3 (C), R402.2
unnamed: C403.2, U401.5 (PD0-OSC_IN), X402.1
unnamed: C404.2, U401.6 (PD1-OSC_OUT), X402.4
VPP: D401.2 (K), P402.1; also elsewhere on the board

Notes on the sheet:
Reset
Motor
JTAG
SW401/SW405/SW406 - alternative footprints and positions, mount only one of them!
RTC XTAL 32.768kHz
CPU XTAL 8MHz

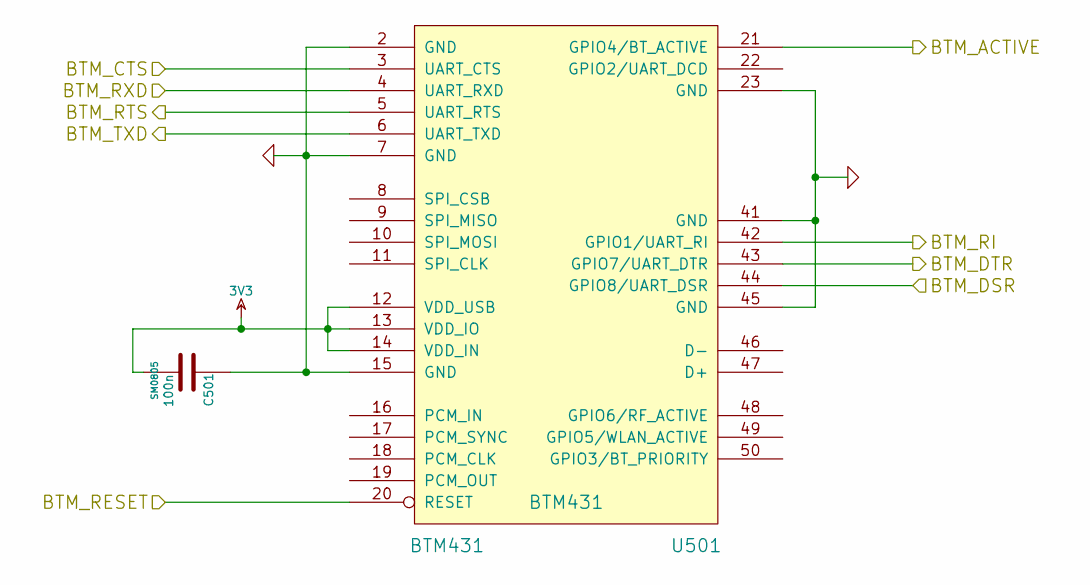
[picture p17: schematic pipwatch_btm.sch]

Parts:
C501: 100n; SM0805
U501: BTM431

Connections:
3V3: C501.2, U501.12 (VDD_USB), U501.13 (VDD_IO), U501.14 (VDD_IN); also elsewhere on the board
/BT Modem/BTM_ACTIVE: U501.21 (GPIO4/BT_ACTIVE); also elsewhere on the board
/BT Modem/BTM_CTS: U501.3 (UART_CTS); also elsewhere on the board
/BT Modem/BTM_DSR: U501.44 (GPIO8/UART_DSR); also elsewhere on the board
/BT Modem/BTM_DTR: U501.43 (GPIO7/UART_DTR); also elsewhere on the board
/BT Modem/BTM_RESET: U501.20 (RESET); also elsewhere on the board
/BT Modem/BTM_RI: U501.42 (GPIO1/UART_RI); also elsewhere on the board
/BT Modem/BTM_RTS: U501.5 (UART_RTS); also elsewhere on the board
/BT Modem/BTM_RXD: U501.4 (UART_RXD); also elsewhere on the board
/BT Modem/BTM_TXD: U501.6 (UART_TXD); also elsewhere on the board
GND: C501.1, U501.2 (GND), U501.7 (GND), U501.15 (GND), U501.23 (GND), U501.41 (GND), U501.45 (GND); also elsewhere on the board

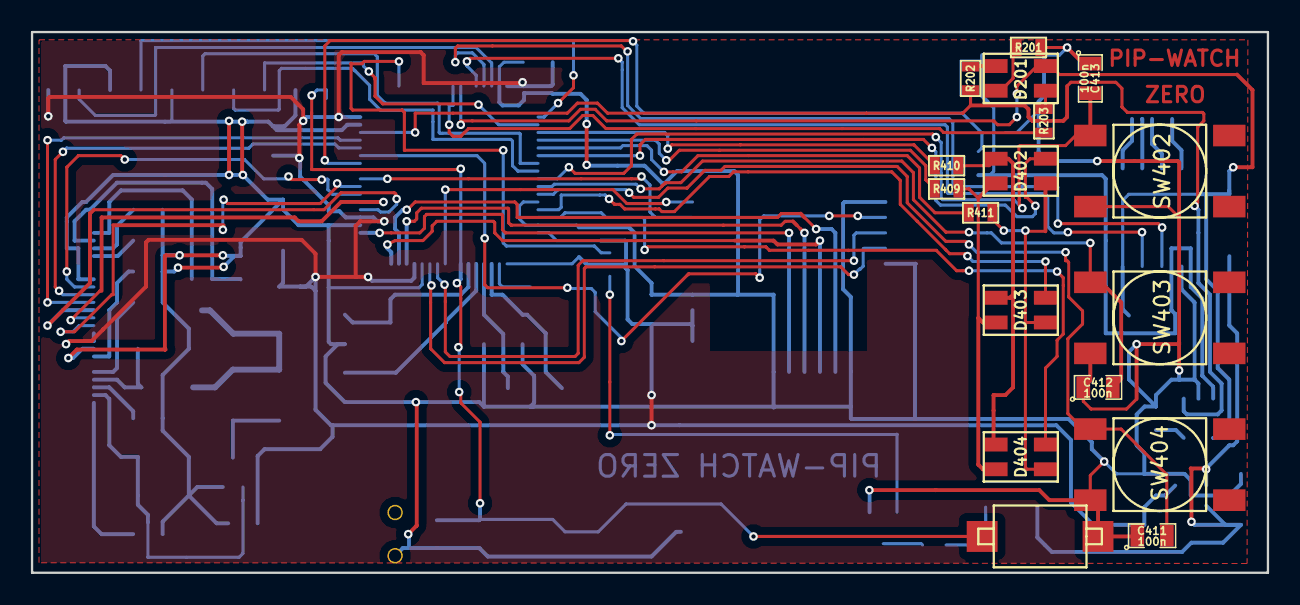
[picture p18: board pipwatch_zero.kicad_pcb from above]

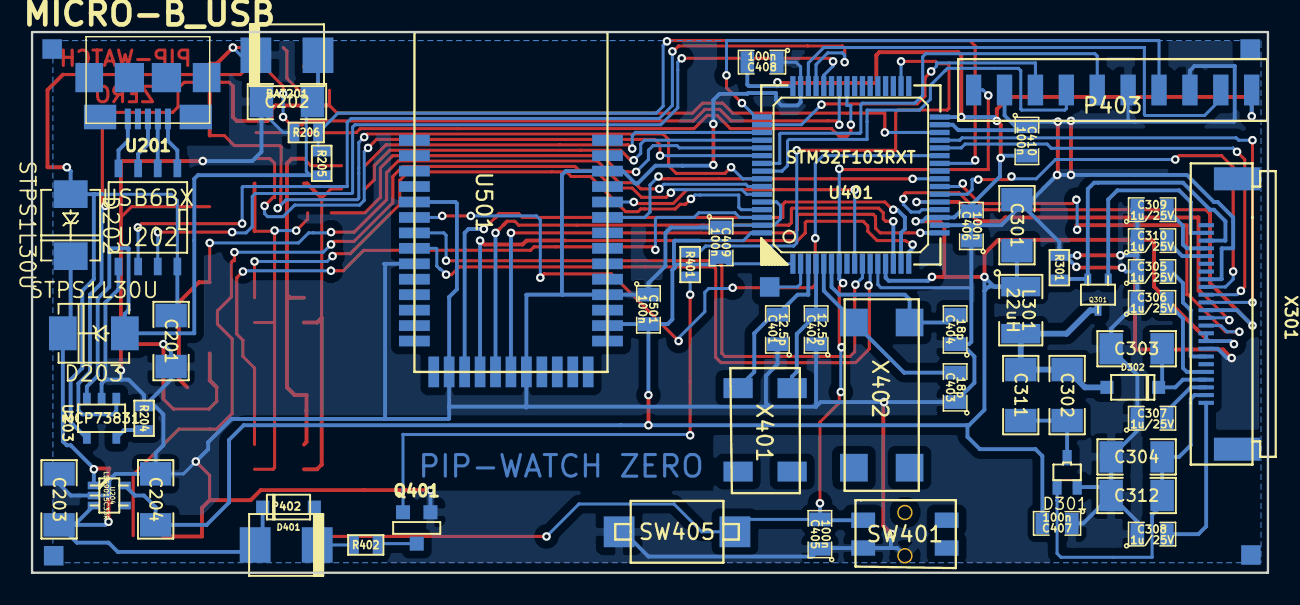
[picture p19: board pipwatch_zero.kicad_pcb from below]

Board: 2 copper layers, 80.0 x 35.0 mm, 77 parts (60 on the bottom side), 72 nets.

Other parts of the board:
1PIN_S_SMD, 1PIN_S_SMD#2, 1PIN_S_SMD#3, 1PIN_S_SMD#4: P***; 1PIN_S_SMD

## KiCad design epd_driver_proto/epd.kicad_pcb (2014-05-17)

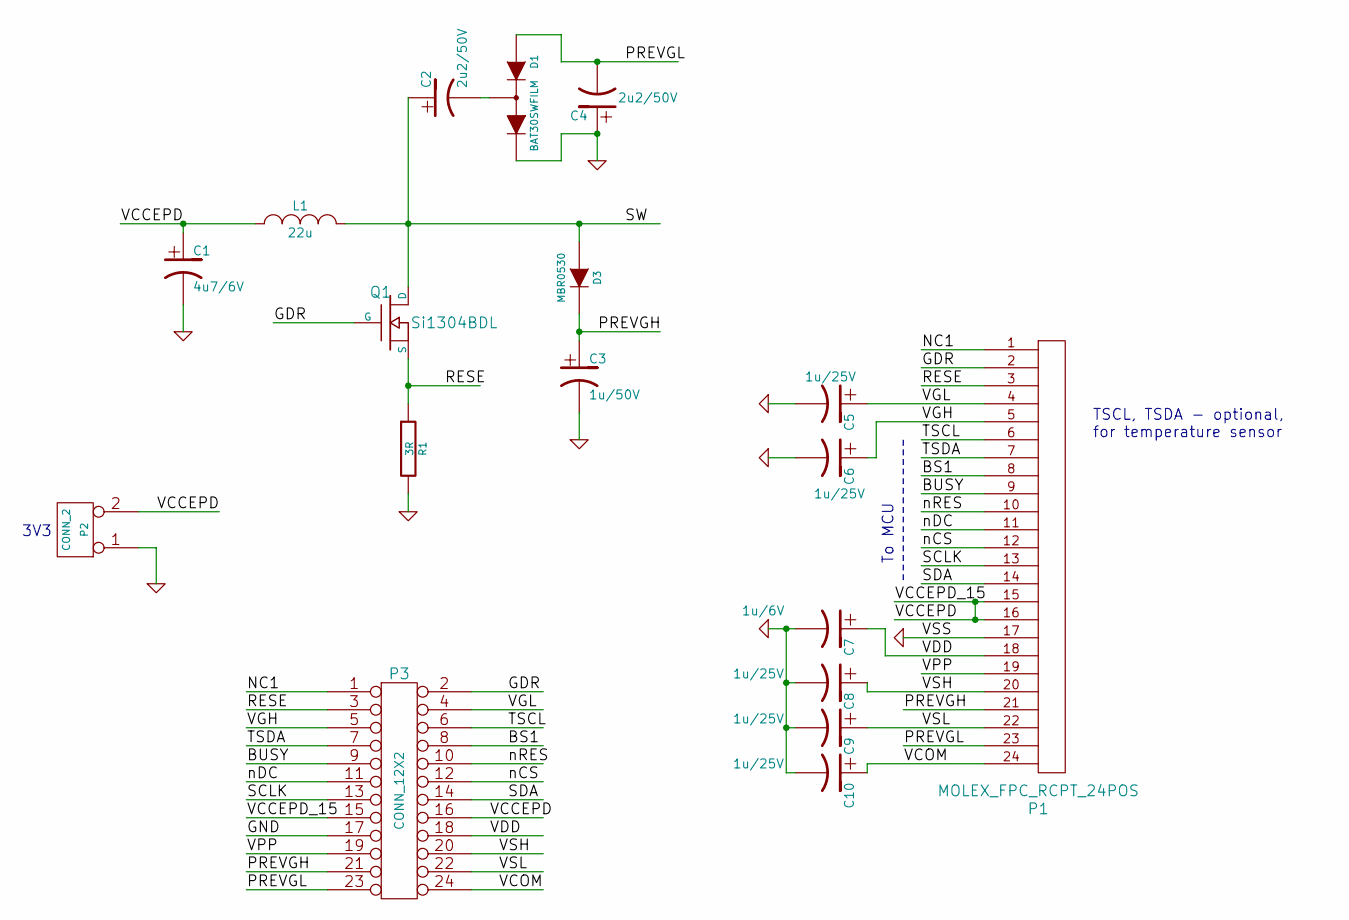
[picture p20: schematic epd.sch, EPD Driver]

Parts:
C1: 4u7/6V
C2, C4: 2u2/50V
C3: 1u/50V
C5, C6, C8, C9, C10: 1u/25V
C7: 1u/6V
D1: BAT30SWFILM
D3: MBR0530
L1: 22u
P1: MOLEX_FPC_RCPT_24POS
P2: CONN_2
P3: CONN_12X2
Q1: Si1304BDL
R1: 3R

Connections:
/BS1: P1.8, P3.8
/BUSY: P1.9, P3.9
/GDR: P1.2, P3.2, Q1.1 (G)
/NC1: P1.1, P3.1
/PREVGH: C3.1, D3.2 (K), P1.21, P3.21
/PREVGL: C4.2, D1.1 (A), P1.23, P3.23
/RESE: P1.3, P3.3, Q1.3 (S), R1.1
/SCLK: P1.13, P3.13
/SDA: P1.14, P3.14
/SW: C2.1, D3.1 (A), L1.2, Q1.2 (D)
/TSCL: P1.6, P3.6
/TSDA: P1.7, P3.7
/VCCEPD: C1.1, L1.1, P1.15, P1.16, P2.2 (PM), P3.15, P3.16
/VCOM: C10.1, P1.24, P3.24
/VDD: C7.1, P1.18, P3.18
/VGH: C6.1, P1.5, P3.5
/VGL: C5.1, P1.4, P3.4
/VPP: P1.19, P3.19
/VSH: C8.1, P1.20, P3.20
/VSL: C9.1, P1.22, P3.22
/nCS: P1.12, P3.12
/nDC: P1.11, P3.11
/nRES: P1.10, P3.10
GND: C1.2, C3.2, C4.1, C5.2, C6.2, C7.2, C8.2, C9.2, C10.2, D1.2 (K), P1.17, P2.1, P3.17, R1.2
unnamed: C2.2, D1.3 (Com)

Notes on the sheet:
TSCL, TSDA - optional, for temperature sensor
To MCU
3V3

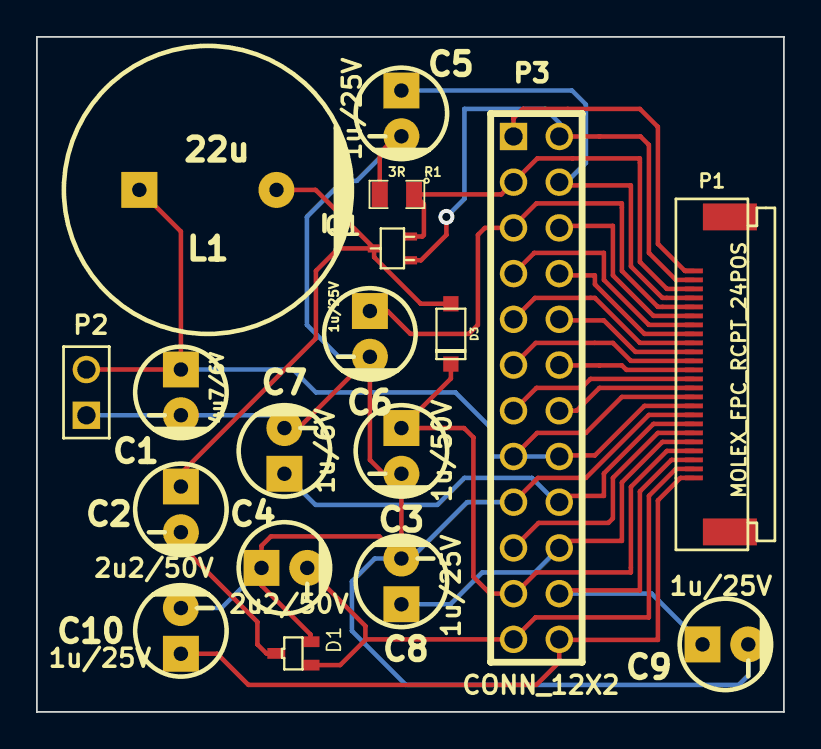
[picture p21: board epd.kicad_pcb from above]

Board: 2 copper layers, 41.5 x 37.5 mm, 18 parts (0 on the bottom side), 25 nets.

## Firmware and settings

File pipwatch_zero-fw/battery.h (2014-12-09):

#ifndef BATTERY_H
#define BATTERY_H

#include "gui_window.h"
#include "utils.h"

/* minimum and maximum battery voltage in milivolts,
 * corresponding to 0 and 100% */
#define VBAT_0_PERCENT      3500
#define VBAT_100_PERCENT    4150

#define USBPOW_Port         GPIOA
#define USBPOW_Pin          GPIO_Pin_9

#define CHARGESTAT_Port     GPIOB
#define CHARGESTAT_Pin      GPIO_Pin_11


/* for batt_state: */
#define BATTERY_UNKNOWN         '?'
#define BATTERY_DISCHARGING     '-'
#define BATTERY_CHARGING        '+'
#define BATTERY_FULL            '='

/* battery voltage in milivolts */
extern int vbat_measured;
extern int vbat_percent;
extern char batt_state;

/* CPU temperature in celsius */
extern int temp_celsius;


/* OS Task - monitoring the battery voltage  */
void BatteryTask(void *pvParameters);

/* IRQ handler for the ADC interrupt */
void ADC_IRQHandler(void);


// --------------------------------------------------------------------------

/* battery symbol graphical dimensions */
#define DEFAULT_BATTERY_WIDTH       20
#define DEFAULT_BATTERY_HEIGHT      8


/* Graphical symbol of a battery */
struct GuiBattery {
    /* the window base class; MUST BE THE FIRST ELEMENT */
    struct GuiWindow win;

    /* battery: voltage, percantage of the charge, charging state */
	int vbat_measured;
	int percent;
	char batt_state;

};


/* drawing callback for battery */
int gui_battery_draw_cb(u8g_t *pu8g, struct GuiWindow *win,
                struct GuiPoint abspos);

/* allocate battery graphical symbol */
struct GuiBattery *gui_battery_alloc(void);


#endif

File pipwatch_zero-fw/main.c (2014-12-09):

#include "main.h"

/* Standard includes. */
#include <string.h>

/* Scheduler includes. */
#include "FreeRTOS.h"
#include "task.h"
#include "queue.h"

/* Library includes. */
#include "stm32f10x_it.h"

/* Driver includes. */
#include "STM32_USART.h"
#include "epd.h"
#include "rtclock.h"
#include "btm.h"
#include "battery.h"
#include "leds.h"
#include "buttons.h"
#include "motor.h"
#include "gui.h"
#include "utils.h"


/* The time between cycles of the 'check' task - which depends on whether the
check task has detected an error or not. */
#define mainCHECK_DELAY_NO_ERROR			( ( TickType_t ) 5000 / portTICK_PERIOD_MS )
#define mainCHECK_DELAY_ERROR				( ( TickType_t ) 500 / portTICK_PERIOD_MS )

/* The LED controlled by the 'check' task. */
#define mainCHECK_LED						( 3 )

/* Task priorities. */
#if 0
#define mainSEM_TEST_PRIORITY				( tskIDLE_PRIORITY + 1 )
#define mainBLOCK_Q_PRIORITY				( tskIDLE_PRIORITY + 2 )
#define mainCHECK_TASK_PRIORITY				( tskIDLE_PRIORITY + 3 )
#define mainFLASH_TASK_PRIORITY				( tskIDLE_PRIORITY + 2 )
#define mainINTEGER_TASK_PRIORITY           ( tskIDLE_PRIORITY )
#define mainGEN_QUEUE_TASK_PRIORITY			( tskIDLE_PRIORITY )
#endif
#define mainECHO_TASK_PRIORITY              ( tskIDLE_PRIORITY + 1 )


/*-----------------------------------------------------------*/

/*
 * Configure the hardware for the demo.
 */
static void prvSetupHardware( void );


/*-----------------------------------------------------------*/


void assert_failed( char *pucFile, unsigned long ulLine );


/*-----------------------------------------------------------*/

int main( void )
{
#ifdef DEBUG
    debug();
#endif

	/* Set up the clocks and memory interface. */
	prvSetupHardware();

    toGuiQueue = xQueueCreate(32, sizeof(struct guievent));

    current_rtime.sec = 0;
    current_rtime.min = 39;
    current_rtime.hour = 21;

    LEDs_Init();
    LEDs_Set(LED0, LED_INTENS_50, LED_INTENS_0, LED_INTENS_0);


	/* Create the 'echo' task, which is also defined within this file. */
    xTaskCreate( BluetoothModemTask, "BTM", 2*configMINIMAL_STACK_SIZE, NULL, mainECHO_TASK_PRIORITY, NULL );

	xTaskCreate( GuiDrawTask, "GuiDraw", 2*configMINIMAL_STACK_SIZE, NULL, mainECHO_TASK_PRIORITY, NULL );

    xTaskCreate( BatteryTask, "Battery", 2*configMINIMAL_STACK_SIZE, NULL, mainECHO_TASK_PRIORITY, NULL );

    xTaskCreate( LEDsTask, "LEDs", 2*configMINIMAL_STACK_SIZE, NULL, mainECHO_TASK_PRIORITY, NULL );

    xTaskCreate( ButtonsTask, "Buttons", 2*configMINIMAL_STACK_SIZE, NULL, mainECHO_TASK_PRIORITY, NULL );

    xTaskCreate( MotorTask, "Motor", 2*configMINIMAL_STACK_SIZE, NULL, mainECHO_TASK_PRIORITY, NULL );


	/* Create the 'check' task, which is also defined within this file. */
	// xTaskCreate( prvCheckTask, "Check", configMINIMAL_STACK_SIZE, NULL, mainCHECK_TASK_PRIORITY, NULL );

    /* Start the scheduler. */
	vTaskStartScheduler();

    /* Will only get here if there was insufficient memory to create the idle
    task.  The idle task is created within vTaskStartScheduler(). */
	for( ;; );
}

/*-----------------------------------------------------------*/


/* FreeRTOS: User defined function executed from within the idle task. */
void vApplicationIdleHook( void )
{
#if 1
    /* Activate the sleep mode - wait for next interrupt. */
    /* Power modes must be configured first!! */
    __WFI();
#endif
}

/*-----------------------------------------------------------*/

/*-----------------------------------------------------------*/

static void prvSetupHardware( void )
{
    NVIC_InitTypeDef NVIC_InitStructure;
    GPIO_InitTypeDef GPIO_InitStruct;

#if 1
	/* RCC system reset(for debug purpose). */
	RCC_DeInit ();

#if 1
    /* Enable HSE. */
	RCC_HSEConfig( RCC_HSE_ON );

	/* Wait till HSE is ready. */
	while (RCC_GetFlagStatus(RCC_FLAG_HSERDY) == RESET)
        ;
#else
    /* Disable HSE */
    RCC_HSEConfig( RCC_HSE_OFF );
#endif

    /* HCLK = SYSCLK. */
    RCC_HCLKConfig( RCC_SYSCLK_Div1 );          // HCLK=8MHz
	// RCC_HCLKConfig( RCC_SYSCLK_Div2 );     

    /* NOTE: update the constant configCPU_CLOCK_HZ to the correct SysTick (HCLK) operating frequency! */

    /* APB2 max 72MHz. PCLK2  = HCLK. */
    // RCC_PCLK2Config( RCC_HCLK_Div1 );
	RCC_PCLK2Config( RCC_HCLK_Div2 );      // PCLK2=4MHz

    /* APB1 max 36MHz. PCLK1  = HCLK/2. */
    // RCC_PCLK1Config( RCC_HCLK_Div2 );       
    RCC_PCLK1Config( RCC_HCLK_Div4 );    // PCLK1=2MHz

	/* ADCCLK = PCLK2/2. */
	RCC_ADCCLKConfig( RCC_PCLK2_Div2 );    // PCLK2/2 = 2MHz

    /* Flash 2 wait state. */
	*( volatile unsigned long  * )0x40022000 = 0x01;

#if 1
    /* PLLCLK = 8MHz * 9 = 72 MHz */
    // RCC_PLLConfig( RCC_PLLSource_HSE_Div1, RCC_PLLMul_9 );   // 8 * 9 = 72MHz
    // RCC_PLLConfig( RCC_PLLSource_HSI_Div2, RCC_PLLMul_9 );     // 8/2 * 9 = 36 MHz
    // RCC_PLLConfig( RCC_PLLSource_PREDIV1, RCC_PLLMul_9 );     // 8 * 9 = 72 MHz (ok)
    // RCC_PLLConfig( RCC_PLLSource_PREDIV1, RCC_PLLMul_2 );     // 8 * 2 = 16 MHz (ok) - MD_VL
    // RCC_PLLConfig( RCC_PLLSource_HSE_Div1, RCC_PLLMul_2 );      // 8 * 2 = 16 MHz
    // RCC_PLLConfig( RCC_PLLSource_HSI_Div2, RCC_PLLMul_4 );      // 8/2 * 4 = 16 MHz
    RCC_PLLConfig( RCC_PLLSource_HSE_Div2, RCC_PLLMul_2 );      // 8 / 2 * 2 = 8 MHz

    // do { } while (1);
    /* Enable PLL. */
	RCC_PLLCmd( ENABLE );          /* BUG: SysReset here, irrespective if HSI or HSE is used!!! */

	/* Wait till PLL is ready. */
	while (RCC_GetFlagStatus(RCC_FLAG_PLLRDY) == RESET)
        ;

    /* Select PLL as system clock source. */
    RCC_SYSCLKConfig (RCC_SYSCLKSource_PLLCLK);

    /* Wait till PLL is used as system clock source. */
    while (RCC_GetSYSCLKSource() != 0x08)
        ;
#endif
#if 0
    /* Select HSI as system clock source. */
    RCC_SYSCLKConfig (RCC_SYSCLKSource_HSI);

    /* Wait till PLL is used as system clock source. */
    while (RCC_GetSYSCLKSource() != 0x00)
        ;
#endif
#if 0
    /* Select HSE-direct as system clock source. */
    RCC_SYSCLKConfig (RCC_SYSCLKSource_HSE);

    /* Wait till PLL is used as system clock source. */
    while (RCC_GetSYSCLKSource() != 0x04)
        ;
#endif



	/* Enable GPIOA, GPIOB, GPIOC, GPIOD, GPIOE and AFIO clocks */
	RCC_APB2PeriphClockCmd(	RCC_APB2Periph_GPIOA | RCC_APB2Periph_GPIOB |RCC_APB2Periph_GPIOC
							| RCC_APB2Periph_GPIOD | RCC_APB2Periph_AFIO, ENABLE );

	/* Set the Vector Table base address at 0x08000000. */
	NVIC_SetVectorTable( NVIC_VectTab_FLASH, 0x0 );

	NVIC_PriorityGroupConfig( NVIC_PriorityGroup_4 );

	/* Configure HCLK clock as SysTick clock source. */
	SysTick_CLKSourceConfig( SysTick_CLKSource_HCLK );
#endif

    /* Update the SystemCoreClock variable based on current register settings */
    SystemCoreClockUpdate();

    /* --------------------------------------------------------------------------- */

    /* Unused pins - pull up */
    /* GPIOA: PA10 */
    GPIO_InitStruct.GPIO_Pin = GPIO_Pin_10;
    GPIO_InitStruct.GPIO_Mode = GPIO_Mode_IPU;
    GPIO_InitStruct.GPIO_Speed = GPIO_Speed_2MHz;
    GPIO_Init(GPIOA, &GPIO_InitStruct);
    /* GPIOB: PB12 PB14 PB15 */
    GPIO_InitStruct.GPIO_Pin = GPIO_Pin_12 | GPIO_Pin_14 | GPIO_Pin_15;
    GPIO_InitStruct.GPIO_Mode = GPIO_Mode_IPU;
    GPIO_InitStruct.GPIO_Speed = GPIO_Speed_2MHz;
    GPIO_Init(GPIOB, &GPIO_InitStruct);
    /* GPIOC: PC0 PC5 PC6 PC7 PC8 PC9 */
    GPIO_InitStruct.GPIO_Pin = GPIO_Pin_0 | GPIO_Pin_5 | GPIO_Pin_6 | GPIO_Pin_7 | GPIO_Pin_8 | GPIO_Pin_9;
    GPIO_InitStruct.GPIO_Mode = GPIO_Mode_IPU;
    GPIO_InitStruct.GPIO_Speed = GPIO_Speed_2MHz;
    GPIO_Init(GPIOC, &GPIO_InitStruct);

    /* ------------------------------------------------------------------------ */

    /* Init SPI and GPIO for EPD */
    epdInitInterface();

	/* APB1 Periph clock enable */
	RCC_APB1PeriphClockCmd( RCC_APB1Periph_PWR | RCC_APB1Periph_BKP, ENABLE );

    /* --------------------------------------------------------------------------- */
    /* RTC */
    /* Enable access to backup registers and RTC */
    PWR_BackupAccessCmd(ENABLE);

    /* Reset backup domain; this allows one-time configuration of RTC clock below. */
    BKP_DeInit();

    /* Enable LSE extenal xtal osci */
    RCC_LSEConfig(RCC_LSE_ON);
    
    /* FIXME: LSE SOMETIMES STOPS WORKING !! - TEMPERATURE ?? */
#if 0
    /* wait until LSE xtal osci is stable */
    while (RCC_GetFlagStatus(RCC_FLAG_LSERDY) == RESET) { }
    /* Set RTC clock source = external 32.768kHz xtal */
    RCC_RTCCLKConfig(RCC_RTCCLKSource_LSE);
#else

    RCC_RTCCLKConfig(RCC_RTCCLKSource_HSE_Div128);

#endif

    /* Enable RTC clock after it has been selected */
    RCC_RTCCLKCmd(ENABLE);

    RTC_ExitConfigMode();
    RTC_WaitForSynchro();
    RTC_WaitForLastTask();

#if 0
    /* set prescaler: divide 32.768kHz LSE XTAL clock by 32768 -> generate 1Hz irq */
    RTC_SetPrescaler(32768);
#else
    /* set prescaler: divide 8MHz/128 HSE clock by 62500 -> generate 1Hz irq */
    RTC_SetPrescaler(62500);
#endif

    RTC_WaitForLastTask();

    /* enable RTC irq */
    RTC_ITConfig(RTC_IT_SEC, ENABLE);

    NVIC_InitStructure.NVIC_IRQChannelPreemptionPriority = configLIBRARY_KERNEL_INTERRUPT_PRIORITY;
    NVIC_InitStructure.NVIC_IRQChannelSubPriority = 0;
    NVIC_InitStructure.NVIC_IRQChannelCmd = ENABLE;
    NVIC_InitStructure.NVIC_IRQChannel = RTC_IRQn;
    NVIC_Init( &NVIC_InitStructure );

    RTC_WaitForLastTask();

    /* ------------------------------------------------------------------------ */
    /* ADC */
#if 1
    RCC_APB2PeriphClockCmd(RCC_APB2Periph_ADC1, ENABLE);

    ADC_InitTypeDef ADC_InitStruct;
    ADC_StructInit(&ADC_InitStruct);
    ADC_InitStruct.ADC_Mode = ADC_Mode_Independent;
    ADC_InitStruct.ADC_ExternalTrigConv = ADC_ExternalTrigConv_None;
    ADC_Init(ADC1, &ADC_InitStruct);

    ADC_Cmd(ADC1, ENABLE);
    ADC_TempSensorVrefintCmd(ENABLE);

    ADC_ITConfig(ADC1, ADC_IT_EOC, ENABLE);
    NVIC_InitStructure.NVIC_IRQChannel = ADC1_2_IRQn;
    NVIC_Init( &NVIC_InitStructure );
#endif

    /* ------------------------------------------------------------------------ */
    /* Buttons */
    /* Configure GPIO pins : PB5,6,7 = Buttons 0, 1, 2 */
    GPIO_InitStruct.GPIO_Pin = GPIO_Pin_5 | GPIO_Pin_6 | GPIO_Pin_7;
    GPIO_InitStruct.GPIO_Mode = GPIO_Mode_IPU;
    GPIO_InitStruct.GPIO_Speed = GPIO_Speed_2MHz;
    GPIO_Init(GPIOB, &GPIO_InitStruct);

    /* USBPOW (PA9) input pull-down */
    GPIO_InitStruct.GPIO_Pin = USBPOW_Pin;
    GPIO_InitStruct.GPIO_Mode = GPIO_Mode_IPD;
    GPIO_InitStruct.GPIO_Speed = GPIO_Speed_2MHz;
    GPIO_Init(USBPOW_Port, &GPIO_InitStruct);

    /* CHARGESTAT (PB11) input pull-up */
    GPIO_InitStruct.GPIO_Pin = GPIO_Pin_11;
    GPIO_InitStruct.GPIO_Mode = GPIO_Mode_IPU;
    GPIO_InitStruct.GPIO_Speed = GPIO_Speed_2MHz;
    GPIO_Init(GPIOB, &GPIO_InitStruct);

    /* configure interrupts from buttons: EXTI 5, 6, 7  */
    EXTI_InitTypeDef EXTI_InitStruct;
    EXTI_InitStruct.EXTI_Line = EXTI_Line5 | EXTI_Line6 | EXTI_Line7 /*| EXTI_Line9*/;
    EXTI_InitStruct.EXTI_Mode = EXTI_Mode_Interrupt;
    EXTI_InitStruct.EXTI_Trigger = EXTI_Trigger_Rising_Falling;
    EXTI_InitStruct.EXTI_LineCmd = ENABLE;
    EXTI_Init(&EXTI_InitStruct);

    /* set EXTI sources */
    GPIO_EXTILineConfig(GPIO_PortSourceGPIOB, GPIO_PinSource5); // BTN0
    GPIO_EXTILineConfig(GPIO_PortSourceGPIOB, GPIO_PinSource6); // BTN1
    GPIO_EXTILineConfig(GPIO_PortSourceGPIOB, GPIO_PinSource7); // BTN2
    // GPIO_EXTILineConfig(GPIO_PortSourceGPIOA, GPIO_PinSource9); // USBPOW

#if 1
    /* all the interrupts go to the EXTI9_5_IRQn IRQ-line */
    NVIC_InitStructure.NVIC_IRQChannel = EXTI9_5_IRQn;
    NVIC_Init( &NVIC_InitStructure );
#endif
    
    /* ------------------------------------------------------------------------ */
    /* LEDs */
    /* Configure GPIO pin : PC10=LEDRK, PC11=LEDGK, PC12=LEDBK Output */
    GPIO_InitStruct.GPIO_Pin = GPIO_Pin_10 | GPIO_Pin_11 | GPIO_Pin_12;
    GPIO_InitStruct.GPIO_Mode = GPIO_Mode_Out_PP;
    GPIO_InitStruct.GPIO_Speed = GPIO_Speed_2MHz;
    GPIO_Init(GPIOC, &GPIO_InitStruct);
    /* set cathodes HI */
    GPIO_SetBits(GPIOC, GPIO_Pin_10 | GPIO_Pin_11 | GPIO_Pin_12);

    /* Configure GPIO pin : PD2=LED1A,  Output */
    GPIO_InitStruct.GPIO_Pin = GPIO_Pin_2;
    GPIO_InitStruct.GPIO_Mode = GPIO_Mode_Out_PP;
    GPIO_InitStruct.GPIO_Speed = GPIO_Speed_2MHz;
    GPIO_Init(GPIOD, &GPIO_InitStruct);
    /* set anode LO */
    GPIO_ResetBits(GPIOD, GPIO_Pin_2);

    /* Configure GPIO pin : PB8=LED2A, PB9=LED3A, Output */
    GPIO_InitStruct.GPIO_Pin = GPIO_Pin_8 | GPIO_Pin_9;
    GPIO_InitStruct.GPIO_Mode = GPIO_Mode_Out_PP;
    GPIO_InitStruct.GPIO_Speed = GPIO_Speed_2MHz;
    GPIO_Init(GPIOB, &GPIO_InitStruct);
    /* set anode LO */
    GPIO_ResetBits(GPIOB, GPIO_Pin_8 | GPIO_Pin_9);

    /* The CHARGEBLUE LED (PA8): Set high-impedence floating -> no current  */
    GPIO_InitStruct.GPIO_Pin = GPIO_Pin_8;
    GPIO_InitStruct.GPIO_Mode = GPIO_Mode_IN_FLOATING;
    GPIO_InitStruct.GPIO_Speed = GPIO_Speed_2MHz;
    GPIO_Init(GPIOA, &GPIO_InitStruct);



    /* ------------------------------------------------------------------------ */
    /* Motors */
    /* Configure GPIO pin : PB13 Output */
    GPIO_InitStruct.GPIO_Pin = MOTOR_Pin;
    GPIO_InitStruct.GPIO_Mode = GPIO_Mode_Out_PP;
    GPIO_InitStruct.GPIO_Speed = GPIO_Speed_2MHz;
    GPIO_Init(MOTOR_Port, &GPIO_InitStruct);
    /* set Motor_1 off */
    GPIO_ResetBits(MOTOR_Port, MOTOR_Pin);


    /* ------------------------------------------------------------------------ */
    /* BTM GPIO Signals */
#if 0
    /* Configure GPIO pin : PC4=BTM_RESET,  Output */
    GPIO_InitStruct.GPIO_Pin = BTM_Reset_Pin;
    GPIO_InitStruct.GPIO_Mode = GPIO_Mode_Out_PP;
    GPIO_InitStruct.GPIO_Speed = GPIO_Speed_10MHz;
    GPIO_Init(BTM_Reset_Port, &GPIO_InitStruct);
    GPIO_SetBits(BTM_Reset_Port, BTM_Reset_Pin);
#endif

    /* ------------------------------------------------------------------------ */
    /* Debugging in low-power modes */
    DBGMCU_Config(DBGMCU_SLEEP | DBGMCU_STOP | DBGMCU_STANDBY, ENABLE);
}

/*-----------------------------------------------------------*/

void vApplicationStackOverflowHook( TaskHandle_t pxTask, char *pcTaskName )
{
	/* This function will get called if a task overflows its stack.   If the
	parameters are corrupt then inspect pxCurrentTCB to find which was the
	offending task. */

	( void ) pxTask;
	( void ) pcTaskName;

	for( ;; );
}
/*-----------------------------------------------------------*/

void assert_failed( char *pucFile, unsigned long ulLine )
{
	( void ) pucFile;
	( void ) ulLine;

    char buf[64];

    strcpy(buf, "ASS-FAIL: ");
    strcat(buf, pucFile);
    strcat(buf, ":");
    itostr(buf+strlen(buf), 8, ulLine);
    strcat(buf, ";");

    printstr(buf);

	for( ;; );
}

/*-----------------------------------------------------------*/

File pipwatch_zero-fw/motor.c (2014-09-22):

#include "motor.h"
#include "stm32f10x_it.h"
#include "task.h"
#include "queue.h"


/* queue */
QueueHandle_t toMotorQueue = NULL;

void MotorTask(void *pvParameters)
{
    /* queue of button presses received in irq handler */
    toMotorQueue = xQueueCreate(16, sizeof(int));

    while (1) {
        int motrun = 0;
        if (xQueueReceive(toMotorQueue, &motrun, portMAX_DELAY) == pdTRUE) {

            if (motrun > MOTOR_DUR_LONG)
                motrun = MOTOR_DUR_LONG;
            if (motrun < 0)
                motrun = 0;

            GPIO_SetBits(MOTOR_Port, MOTOR_Pin);
            vTaskDelay(( ( TickType_t ) motrun ));
            GPIO_ResetBits(MOTOR_Port, MOTOR_Pin);
        }
    }
}


void Motor_Pulse(int dur)
{
    if (toMotorQueue) {
        xQueueSend(toMotorQueue, &dur, 0);
    }
}

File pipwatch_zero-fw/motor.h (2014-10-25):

#ifndef MOTOR_H
#define MOTOR_H

#include "FreeRTOS.h"

#define MOTOR_Port          GPIOB
#define MOTOR_Pin           GPIO_Pin_13


#define MOTOR_DUR_SHORT         (( TickType_t ) 50 / portTICK_PERIOD_MS)
#define MOTOR_DUR_MEDIUM         (( TickType_t ) 150 / portTICK_PERIOD_MS)
#define MOTOR_DUR_LONG         (( TickType_t ) 400 / portTICK_PERIOD_MS)

// #define MOTOR_ACT_OFF           0
// #define MOTOR_ACT_FULL          100

void MotorTask(void *pvParameters);

void Motor_Pulse(int dur);

#endif

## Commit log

2014-05-17 EPD Driver prototype board with MOLEX FPC, pin header, and mosfet
    [epd.kicad_pcb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]
2014-05-17 documentation, license
    [bluetooth_modem-at_commands.ods]
2014-05-19 global bom; a picture of aspects
    [Global_BOM.ods]
2014-06-18 updated BOM, added pdf of the battery charger MCP73831T
    [Global_BOM.ods]
2014-06-29 stm32f103_rtos_u8glib_epd: epd_driver_proto(hw) + STM32F103 + FreeRTOS + u8g = draws simple text
2014-07-22 fix usart2: rcc, basic bluetooth modem
    [STM32_USART.c, main.c]
2014-07-22 u8g_epd_btm: Prints text received over BT modem on EPD. Basic RTC config.
2014-07-23 power saving: WFI in Idle, slow clock. Clock face drawing
2014-07-26 stm32f103_rtos_u8g_epd_btm: rtclock, reorganize files
2014-07-26 battery voltage measurement
2014-07-29 update global BOM
    [Global_BOM.ods]
2014-07-29 pipwatch_zero: started hardware schema
    [pipwatch_zero.sch, pipwatch_zero_cpu.sch, pipwatch_zero_power.sch]
2014-08-13 hw drawing (started), sw fixes for presentation
    [pipwatch_zero.sch, pipwatch_zero_cpu.sch, pipwatch_zero_power.sch]
2014-08-23 pipwatch_zero: basic schema complete
    [pipwatch_btm.sch, pipwatch_epd.sch, pipwatch_zero.sch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]
2014-08-24 pipwatch_zero: footprints
    [BOM_pipwatch_zero.ods, pipwatch_btm.sch, pipwatch_epd.sch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]
2014-08-31 pipwarch-zero: started layout
    [pipwatch_btm.sch, pipwatch_epd.sch, pipwatch_zero.kicad_pcb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]
2014-08-31 pipwatch_zero layout complete
    [pipwatch_btm.sch, pipwatch_zero.kicad_pcb, pipwatch_zero.sch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]
2014-09-03 pipwatch_zero hw02, sent to pragoboard
    [BOM_pipwatch_zero.ods, pipwatch_btm.sch, pipwatch_epd.sch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]
2014-09-07 hw02 schematic pdf
2014-09-14 sw pipwatch_zero_rtos_u8g_epd_btm; somewhat working, bugs in hw
    [BOM_pipwatch_zero.ods, pipwatch_btm.sch, pipwatch_epd.sch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]
2014-09-18 auto-off LEDs after a timeout
2014-09-18 leds comments
2014-09-20 new bluetooth works; buttons via irq still dont
2014-09-21 buttons work
2014-09-22 bt-modem work, motor
2014-09-26 btm.c: low-power optimization: page-scan interval 1.25s
2014-10-01 do not print CONNECT, RING and NO CARRIER to the display
2014-10-05 rename dirs; protocol work
    [BOM_pipwatch_zero.ods, pipwatch_btm.sch, pipwatch_epd.sch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]
2014-10-22 fixed jtag low-power issue; app-link work
    [btm.c, main.c]
2014-10-23 epd experiments; basic sms print
2014-12-13 add LUT data from STM3232323232323232323232323232323232323232323232323232323232323232Cube0L
